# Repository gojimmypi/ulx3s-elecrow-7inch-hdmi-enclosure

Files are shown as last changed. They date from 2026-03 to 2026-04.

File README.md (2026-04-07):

# ULX3S Elecrow 7 inch HDMI Display Enclosure

This is an enclosure for the [ULX3S FPGA + ESP32](https://radiona.org/ulx3s/) development and educational board
for use with the [Elecrow 7 inch HDMI display](https://www.elecrow.com/rc070s-7-inch-1024-600-ips-hdmi-capacitive-touch-monitor.html),
such as [this one available on Amazon](https://www.amazon.com/dp/B08FMNDDSL).



The enclosure is not perfect. Some minor remaining ideas for improvement are in the [To-Do list](./TODO.md).

See related links:

- [ULX3S Crowd Supply Campaign](https://www.crowdsupply.com/radiona/ulx3s)
- [ULS3S from Mouser](https://www.mouser.com/c/?q=ulx3s)
- [Elecrow HDMI display from Amazon](https://www.amazon.com/dp/B08FMNDDSL) on Amazon
- [ulx3s.github.io](https://ulx3s.github.io/) for some sample ULX3S projects

## Warnings

- Choking hazard for small parts. Keep away from children and pets.
- Don't use external and internal HDMI concurrently. Pick one.
- Don't use USB Touch and USB Power connectors at the same time. Pick one.
- Experimental FPGA Programming of an HDMI display may result in pseudo "burn-in". See [YouTube video](https://www.youtube.com/watch?v=WJaRHJX4xYA) to resolve.

## Specification Summary

Designed with Autodesk Fusion for the [Prusa MK3S 3D Printer](https://help.prusa3d.com/product/mk3s) using PETG Filament.
Sliced with PrusaSlicer 2.9.4.

The latest [Prusa MK3S](https://help.prusa3d.com/product/mk3s) firmware was used: [`MK3S_MK3S+_FW_3.14.1_MULTILANG.hex`](https://www.prusa3d.com/downloads/firmware/prusa3d_fw_3_14_1_MK3S.zip).
There's a copy [here](./firmware/). Note this version is completely intolerant to intermittent sensor failures. See [MINTEMP BED error](https://help.prusa3d.com/article/mintemp-error-and-mintemp-bed_2169).

#### Default Fusion settings

- Refinement: Medium
- Surface Deviation: 0.036706 mm
- Normal Deviation: 15.00 (angular tolerance in degrees)
- Maximum Edge: 231.60045 mm (no practical limit)
- Aspect Ration: 21.5 (Controls how "skinny" triangles are allowed to be)

#### 3D Printer Settings

- Material: PETG
- Ambient temperature: > 75F
- Print Setting: 0.15 Quality (each layer thickness)
- Nozzle: 0.4 mm
- Filament: 1.75 mm
- First Layer: 240 degrees C
- Other layers: 236 degrees C
- Bed: 85 degrees C
- Otherwise defaults in PrusaSlicer version 2.9.4

Note the 0.4 mm nozzle and 0.15 layer height are coded in the Fusion parameters. ymmv with other print settings.

## 3D Printing Files

There are Autodesk Fusion STL files in the [STL](./STL/README.md) directory for printing to any device.

Prototypes were all created using PETG filament. Other filaments may be used. Note the snap-in nature of
the display expects the right (audio) side of the enclosure to have a bit of flex during assembly.

#### Prusa Files

The Pruse Slicer Project files and G-Code are in the [Prusa](./Prusa/README.md) directory.
Included are `PrusaSlicer_config_bundle.ini` files for the MK3S, but should adapt easily to other printers.

To [get started](./QUICK_START.md) quickly, printing all parts for the Prusa slicer, see:

- `Enclosure Display Side.3mf`<br />
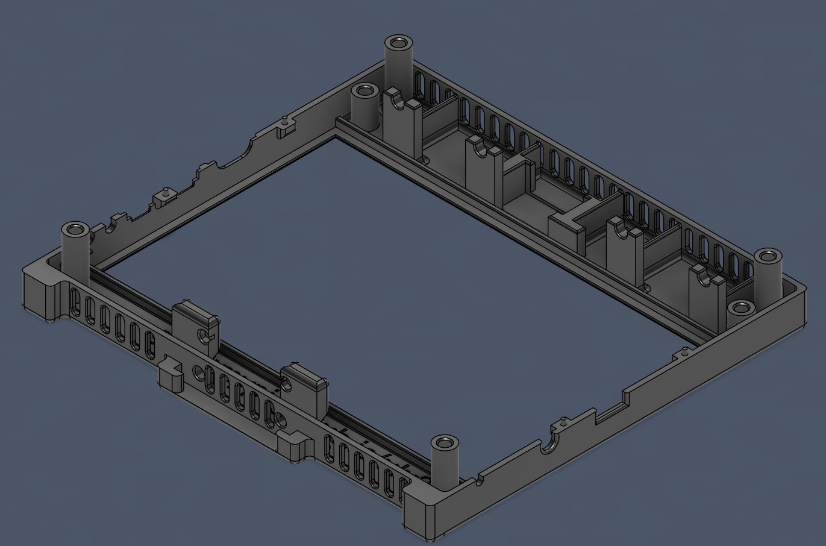
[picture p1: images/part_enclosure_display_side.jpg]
part_enclosure_display_side
   
- `Enclosure ULX3S Side.3mf`<br />
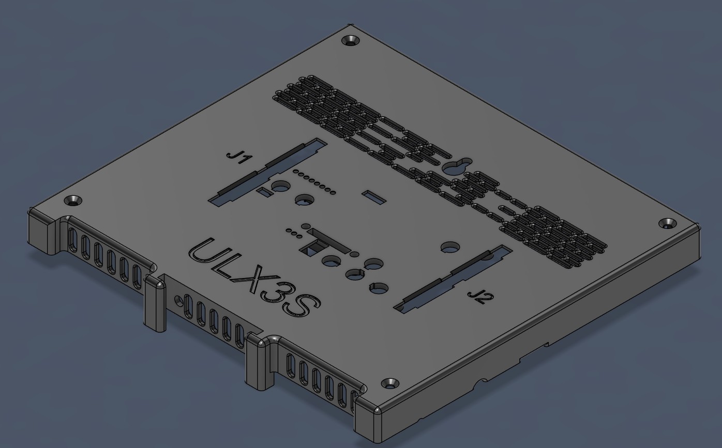
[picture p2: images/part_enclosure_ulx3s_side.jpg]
part_enclosure_ulx3s_side
 
- `Small parts.3mf`<br />
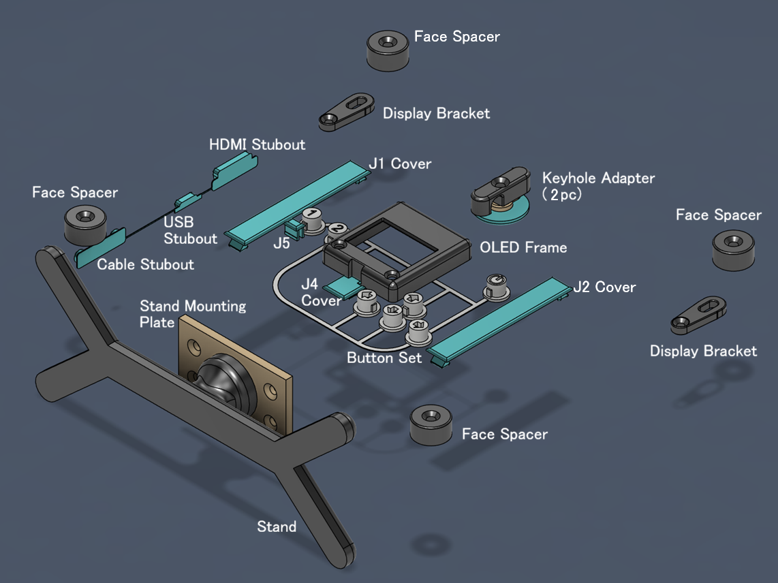
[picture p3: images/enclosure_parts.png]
part_ULX3S To RPi Elecrow Adapter
  
- `Adapter Base Plate Set.3mf`<br />
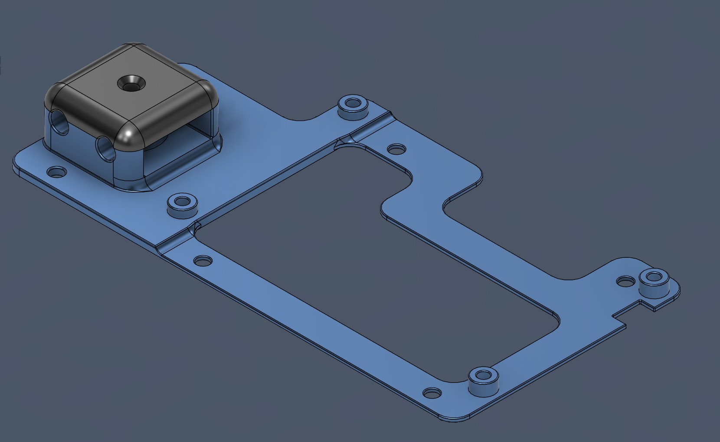
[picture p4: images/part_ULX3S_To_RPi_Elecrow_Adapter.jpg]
part_ULX3S To RPi Elecrow Adapter
  

Note that the buttons are includes in the small parts set. If a separate color is desired for only the buttons, see the `Button Set` files. <br />

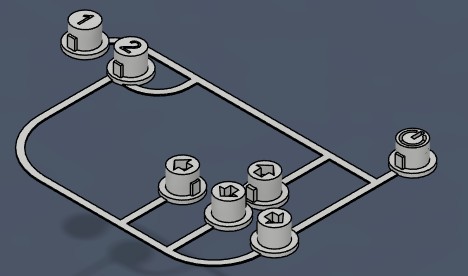
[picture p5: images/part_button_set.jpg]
part_button_set
- 

The "0.15 Quality" has some critical changes in the `User Presets - 0.15mm QUALITY @MK3 - ULX3S Project`
that were observed to make a difference between print success and failure.

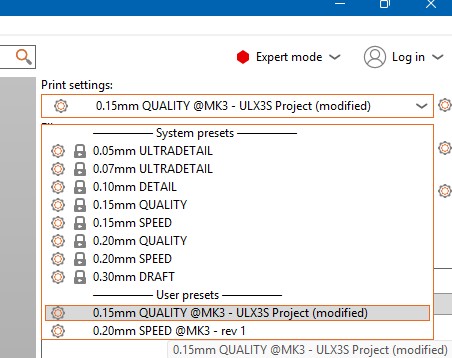
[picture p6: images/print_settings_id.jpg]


In particular not these changes from defaults:

- print_settings_id = 0.15mm QUALITY @MK3 - ULX3S Project

- seam_position = rear

- brim_width = 5 (can be set to zero if in a warm, stable environment)

- first_layer_speed = 15

- first_layer_extrusion_width = 0.5

- elefant_foot_compensation = 0.05

Other settings to consider:

- Increase infill to 20 - 30% (main print settings)

- Increase the number of perimeters from 2 to 3. (Print Settings - Layers and Perimeters - Vertical shells - Perimeters)

## Compatibility Issues

The Elecrow display was designed for the Raspberry Pi, not the ULX3S. As such there are some minor physical positioning items to consider:

- USB2 / US2 vs Speaker.

  When mounted directly on the Elecrow display, the second USB connector on the ULX3S does not have room to be plugged in with the default speaker position.

  Consider rotating the speaker at an angle to ensure the USB cable can be inserted.

  Plug in the speakers, mount the ULX3S to the display first, then consider USB cable routing before securing speakers to display.

- J2 Header vs Fan Header

  The onboard fan connector header for the Elecrow display fan is directly under some of the J2 header pins.
  The fit is so tight that soldered leads may need to be trimmed and/or the plastic header trimmed.

  It is unlikely that the fan header connector can be used. No fan is typically included with the display.

- Audio

  The Elecrow HDMI Display will typically pass through audio on the HDMI interface. For an FPGA board such as the ULX3S, the audio would _need to be implemented in HDL_.

  The external audio connector is for optional headphones.

  There's also an onboard audio connector for the ULX3S. There's an optional exit hole to route the audio out from the ULX3S.

- HDMI

  The ULX3S has a pin-_compatible_ GPDI (General-Purpose Differential Interface). To use this with an HDMI display, the appropriate HDL needs to be implemented on the FPGA. See the [Bruno Levy example](https://github.com/BrunoLevy/learn-fpga/tree/master/Basic/ULX3S/ULX3S_hdmi).

  Do **NOT** use the side panel Elecrow Display HDMI concurrently with the ULX3S connected internally.

  The mini-PC Board HDMI-to-HDMI connector is not specified as being included on all Elecrow product listing at various vendors. If _not_ included, there's room to use an [A1-A1 FPC (Flexible PC)](https://www.amazon.com/dp/B01787KZVG) HDMI Cable. Note some A1 cables reverse one of the HDMI connectors. The desired orientation is having both narrow sides in the same orientation:

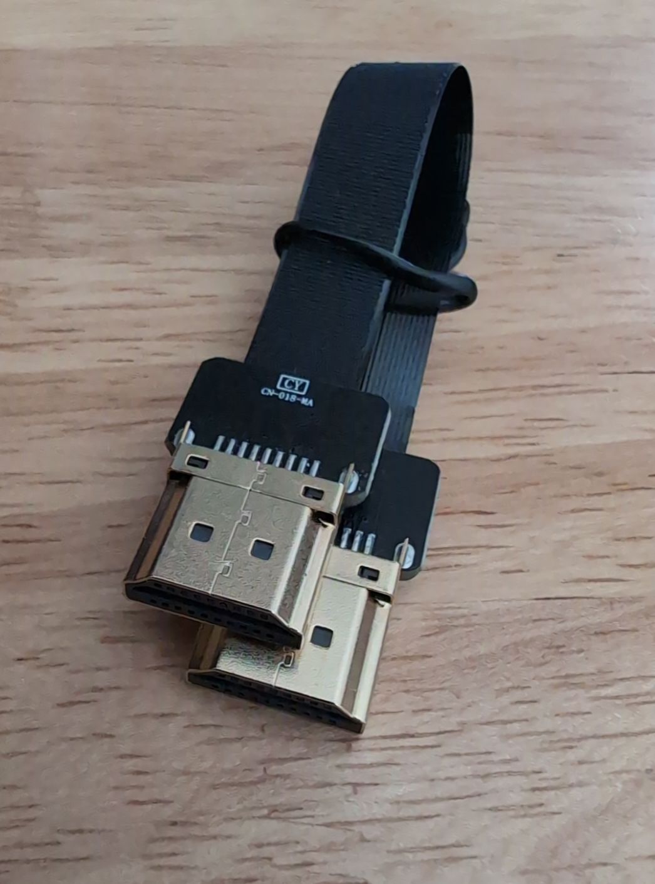
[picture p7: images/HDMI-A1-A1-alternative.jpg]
HDMI A1-A1 alternative
  

  Note when using the ribbon cable HDMI connector, there may be mechanical interference with optional internal fan and/or keyhole mount.

## Features

- Buttons for ULX3S: PWR, F1, F2, Left, Right, Up, Down
- Light pipe mounting blocks for `D0` - `D7` (blinky) and `D18` (PWREN), `D9` (TXLED), `D22` (WIFI): Tight fit 2mm fiber optic cable max diameter.
- External panel access to J1 and J2 GPIO 40 pin header with optional cover.
- External panel access to J3 (GND and WIFI_OFF: ESP32 EN)
- External panel access to J4 JTAG 6 pin header: `3v3`, `GND`, `TDO`, `TDI`, `TCK`, `TMS`.
- External Panel access to J5 VJ1 `+3v3` and `+2v5`, pin 2 is `2V5_3V3` (note: covered when using OLED frame)
- External Elecrow HDMI connection. (**WARNING**: Not to be used concurrently with ULX3S HDMI)
- External Micro-B USB connector for display power.
- External Micro-B USB connector for optional display touch control.
- External access to Display Brightness / Volume control.
- External SRRS mounting hole for ULX3S audio output.
- Audio: 3.5 mm jack with 4 contacts (analog stereo + digital audio or composite video)
- Optional mounting stand.
- Optional OLED display frame for [0.95" 7 pin SPI SSD1331 OLED Display](https://www.amazon.com/dp/B0711RKXB5/)
- Optional feet (same thickness as the OLED display frame) for using the display horizontally during development.
- Optional keyhole for wall mounting: Slightly offset to one side to balance internals.
- Optional internal slot for [25mm x 10mm 5V fan](https://www.amazon.com/dp/B07KRX9F99).
- Optional face screws for securing ULS3S directly to enclosure. Hole is nearly to surface, poke to use with 4 mm standoffs.
- Internal USB cable routing.
- Internal FPC HDMI cable routing.
- Exit holes for USB cables routed internally from ULX3S. See adapter strain relief block.
- Adjustable positioning for the display. See left and right display brackets.
- Air vents in the top and bottom. (assuming a vertical orientation of display)
- Optional `(Hex Head)`-suffixed files for Stand Mounting Plate and Display Brackets where screw clearance is critical. The default is Philips.

## Assembly

The enclosure was designed to have the ULX3S mounted inside. This means that the USB connectors require internal cable routing.

See [ASSEMBLY.md](./ASSEMBLY.md) for further details.

### Display

The display snaps into place. There is a bit of up-down play available, as the technical diagram did not reference the display positon with respect to the attached display driver PC board. Once snapped into place, manually align the USB ports on the left and the audio cable on the right. Plus in a USB cable and audio cable to ensure proper alignment, then fix the display in place with the brackets.

Insert a USB Micro-B cable on one side of the enclosure and ideally an audio cable on the other to ensure alignment of the display board with the enclosure.

Once alignment has been verified, install the display mounting brackets and tighten the screws.

### Speakers

Ensure the ULX3S board is mounted first. There's a tight fit between the speaker and PC Board.

### HDMI Connection

There's a tight vertical clearance between the HDMI-HDMI connector board at the underside of the ULX3S. Consider insulsting kapton or electrical tape.

**WARNING** Do not use the external HDMI connection while the ULX3S is connected internally. Consider keeping a cover in place.

## Files

- [bitfiles](./bitfiles/README.md) - Prebuilt FPGA files to get started quickly.
- [firmware](./firmware/README.md) - Firmware `.hex` files for Prusa MK3S printers.
- [Fusion/ExportedParameters.csv](./Fusion/ExportedParameters.csv) - Parameters defined in Autodesk Fusion.
- [Prusa](./Prusa/README.md) - Prusa Slicer Projects and G-Code for the MK3S.
- [Prusa/PrusaSlicer_config_bundle.ini](./Prusa/PrusaSlicer_config_bundle.ini) - Prusa MK3S settings used.
- [STL](./STL/README.md) - Enclosure and all parts in STL format printed from Autodesk Fusion.

## Published Files

Currently the original official; files are only located at <https://github.com/gojimmypi/ulx3s-elecrow-7inch-hdmi-enclosure>

[x] <https://cults3d.com/en/3d-model/various/ulx3s-hdmi-enclosure-for-the-elecrow-7-inch-display>

TODO publish to other locations:

- <https://www.printables.com/@gojimmypi_17688>
- <https://www.thingiverse.com/gojimmypi/designs>
- <https://www.etsy.com/people/gojimmypi>
- <https://www.elecrow.com/share-projects.html>
- <https://grabcad.com/gojimmypi-1/models>
- <https://thangs.com/designer/gojimmypi>
- <https://www.myminifactory.com/users/gojimmypi>
- <https://makerworld.com/en/@gojimmypi>

## License

See [LICENSE](./LICENSE). In short:

The [Creative Commons Attribution - NonCommercial - ShareAlike 4.0 International (CC BY-NC-SA 4.0) license](https://creativecommons.org/licenses/by-nc-sa/4.0/)
lets anyone copy, share, and modify this enclosure design worldwide and royalty-free, as long as users

- (1) give proper attribution
- (2) use it only for non-commercial purposes
- (3) distribute any modified versions under the same license (ShareAlike).

It is irrevocable provided users follow the terms, does not grant patent or trademark rights,
and includes strong warranty and liability disclaimers (the work is provided "as-is").
If someone violates the terms, their rights terminate automatically but can be reinstated
if they fix the issue within 30 days. In short, it allows open collaboration and remixing,
but blocks commercial use and requires derivatives to stay under the same non-commercial license.

A commercial license is available. Contact me: <https://gojimmypi.github.io/>

## Links

- [Prusa How to update firmware (MK3S+/MK3S/MK3)](https://help.prusa3d.com/article/how-to-update-firmware-mk3s-mk3s-mk3_2227)
- [CrowdSupply ulx3s](https://www.crowdsupply.com/radiona/ulx3s)
- [Prusa Help: Layers and perimeters, detect thin walls](https://help.prusa3d.com/article/layers-and-perimeters_1748#detect-thin-walls)
- [Prusa Help: Seam position](https://help.prusa3d.com/article/seam-position_151069)
- [Digilent Pmod and FPGA: Connection Guide](https://digilent.com/blog/where-to-plug-in-your-pmod-fpga/)
- [openFPGALoader WEB interface - ofl.trabucayre.com](https://ofl.trabucayre.com/), from [github.com/trabucayre/openFPGALoader](https://github.com/trabucayre/openFPGALoader)
- [ULX3S examples from the Legendary Lawrie Griffiths](https://github.com/lawrie/ulx3s_examples/tree/master)

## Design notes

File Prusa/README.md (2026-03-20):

# Prusa Files for the ULX3S Elecrow 7 Inch HDMI Enclosure

## Project Files

### Prusa Slicer Main Body and Print Set Projects

- Enclosure Display Side.3mf
- Enclosure ULX3S Side.3mf

### Prusa Slicer Individual Part Projects

- Adapter Base Plate Set.3mf
- Adapter Base Plate Spacer  2.3mf
- Adapter Base Plate Spacer.3mf
- Adapter Base Plate.3mf
- Button Set.3mf
- Display Bracket Left.3mf
- Display Bracket Right.3mf
- Enclosure Display Side.3mf
- Enclosure ULX3S Side.3mf
- HDMI Stubout.3mf
- J1 Cover.3mf
- J2 Cover.3mf
- J3 Cover.3mf
- J4 Cover.3mf
- Keyhole External Adapter.3mf
- Keyhole Face Insert.3mf
- Keyhole Internal Adapter.3mf
- Light Pipe Sample.3mf
- OLED Frame.3mf
- Rear Foot 1.3mf
- Rear Foot 2.3mf
- Rear Foot 3.3mf
- Rear Foot.3mf
- Small parts.3mf
- Stand Mounting Plate.3mf
- Stand.3mf
- ULX3S Face Covers.3mf
- USB Restraint Cap.3mf

### Prusa Slicer Individual Part Mockup Project

- Display Mockup.3mf
- Keychain Ring Mockup.3mf

## G-Code Files

The G-Code files were generated for a Prusa MK3S+ printer.

### Prusa Slicer Main Body and Print Set G-Code

When printing, the two enclosure halves and the small parts set can be used instead of printing each part individually.

The Adapter Base Plat Set is included in the Small Parts and can also be printed separately as a set.

- Adapter Base Plate Set_0.15mm_PETG_MK3S_1h21m.gcode
- Enclosure Display Side_0.15mm_PETG_MK3S_7h5m.gcode
- Enclosure ULX3S Side_0.15mm_PETG_MK3S_8h55m.gcode
- Small parts_0.15mm_PETG_MK3S_5h5m.gcode

### Prusa Slicer Individual Part G-Code

- Adapter Base Plate Spacer  2_0.15mm_PETG_MK3S_5m.gcode
- Adapter Base Plate Spacer_0.15mm_PETG_MK3S_5m.gcode
- Adapter Base Plate_0.15mm_PETG_MK3S_59m.gcode
- Button Set_0.15mm_PETG_MK3S_19m.gcode
- Display Bracket Left_0.15mm_PETG_MK3S_6m.gcode
- Display Bracket Right_0.15mm_PETG_MK3S_6m.gcode
- Enclosure Display Side_0.15mm_PETG_MK3S_7h5m.gcode
- Enclosure ULX3S Side_0.15mm_PETG_MK3S_8h55m.gcode
- HDMI Stubout_0.15mm_PETG_MK3S_6m.gcode
- J1 Cover_0.15mm_PETG_MK3S_7m.gcode
- J2 Cover_0.15mm_PETG_MK3S_7m.gcode
- J3 Cover_0.15mm_PETG_MK3S_2m.gcode
- J4 Cover_0.15mm_PETG_MK3S_3m.gcode
- Keyhole External Adapter_0.15mm_PETG_MK3S_12m.gcode
- Keyhole Face Insert_0.15mm_PETG_MK3S_3m.gcode
- Keyhole Internal Adapter_0.15mm_PETG_MK3S_5m.gcode
- OLED Frame_0.15mm_PETG_MK3S_20m.gcode
- Rear Foot 1_0.15mm_PETG_MK3S_11m.gcode
- Rear Foot 2_0.15mm_PETG_MK3S_11m.gcode
- Rear Foot 3_0.15mm_PETG_MK3S_11m.gcode
- Rear Foot_0.15mm_PETG_MK3S_11m.gcode
- Stand Mounting Plate_0.15mm_PETG_MK3S_24m.gcode
- Stand_0.15mm_PETG_MK3S_1h16m.gcode
- ULX3S Face Covers_0.15mm_PETG_MK3S_16m.gcode
- USB Restraint Cap_0.15mm_PETG_MK3S_18m.gcode

### Prusa Slicer Individual Part Mockup G-Code

- Display Mockup_0.15mm_PETG_MK3S_5h14m.gcode
- Keychain Ring Mockup_0.15mm_PETG_MK3S_11m.gcode
- Light Pipe Sample_0.15mm_PETG_MK3S_19m.gcode

### Prusa Slicer MK3S Settings

- PrusaSlicer_config_bundle v1.ini
- PrusaSlicer_config_bundle.ini
- PrusaSlicer_config_bundle_original.ini
-

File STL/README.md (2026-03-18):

# STL Files

- Button Set.stl
- Display Bracket Left.stl
- Display Bracket Right.stl
- Display Mockup.stl
- Enclosure Display Side.stl
- Enclosure ULX3S Side.stl
- HDMI Stubout.stl
- J1 Cover.stl
- J2 Cover.stl
- J3 Cover.stl
- J4 Cover.stl
- Keychain Mockup.stl
- Keyhole External Adapter.stl
- Keyhole Face Insert.stl
- Keyhole Internal Adapter.stl
- Light Pipe Sample.stl
- OLED Frame.stl
- Rear Foot 1.stl
- Rear Foot 2.stl
- Rear Foot 3.stl
- Rear Foot.stl
- Stand Mounting Plate.stl
- Stand.stl
- ULX3S Mockup.st

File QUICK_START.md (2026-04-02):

# Quick Start

The [ASSEMBLY](./ASSEMBLY.md) instructions contain details for the various options.

There are only 3 essential parts:

| Part | Description |
| ---- | --- |
| <a href="./images/part_ULX3S_To_RPi_Elecrow_Adapter.jpg" target="_blank">part_ULX3S To RPi Elecrow Adapter</a> | Adapter Mounting Bracket with internal USB restraint |
| <a href="./images/part_enclosure_ulx3s_side.jpg" target="_blank">part_enclosure_ulx3s_side</a> | Enclosure ULX3S Side |
| <a href="./images/part_enclosure_display_side.jpg" target="_blank">part_enclosure_display_side</a> | Enclosure Display Side |

The holes for heat set inserts are size for the type with a little lip on one end as seen on the left:

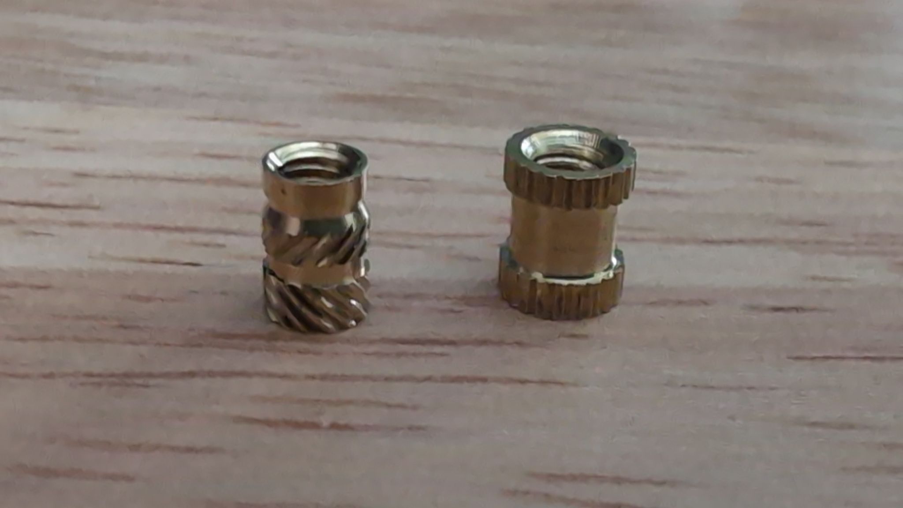
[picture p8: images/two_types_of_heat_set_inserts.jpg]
two types of heat set inserts


Most screws are [Philips M3](https://www.amazon.com/dp/B0FZTYBXPY). The HDMI Display use M2.5, and the OLED mount uses M2.

[These M3 inserts](https://www.amazon.com/dp/B0FWWW8VP1) were used:

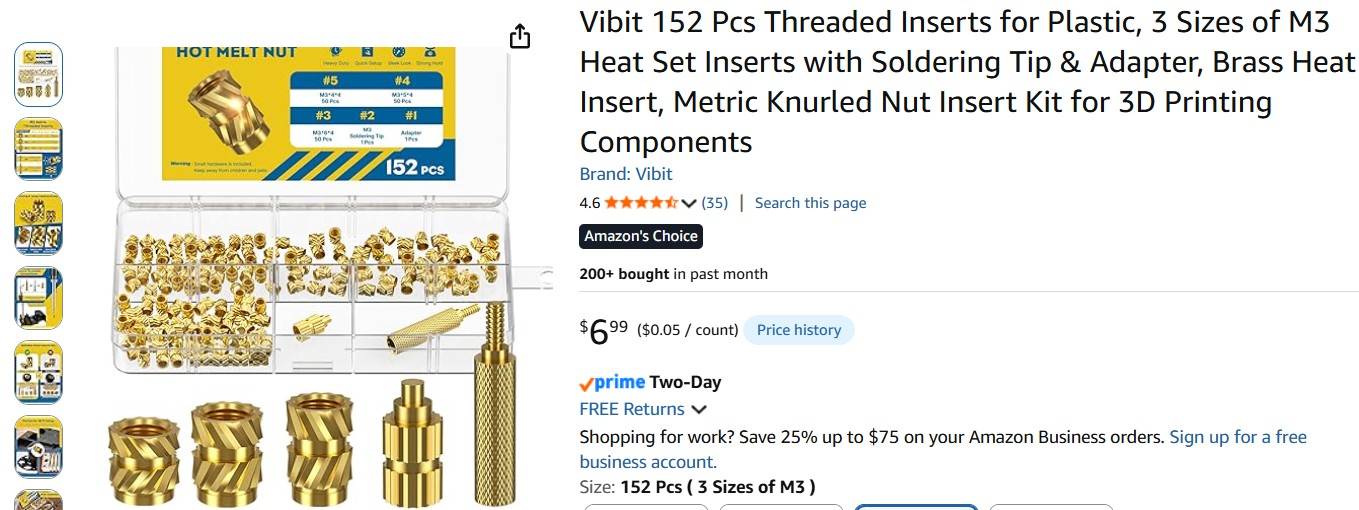
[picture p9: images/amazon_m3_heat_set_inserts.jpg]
amazon m3 heat set inserts


## Assembly

Secure the mounting adapter to the display, then attach the ULX3S to the adapter.

Be sure to install the A1-A1 HDMI connector between the ULX3S and the display.

See the [ASSEMBLY](./ASSEMBLY.md) instructions for more details.

## Bit files

See the pre-built binaries in the [bitfiles](./bitfiles/README.md) directory.

```bash
fujprog HDMI_test_hires.bit
```

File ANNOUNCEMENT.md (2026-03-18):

# New 3D Printable ULX3S Enclosure for the Elecrow 7 inch HDMI Display

The ULX3S community continues to build amazing projects ranging from retrocomputers to FPGA graphics demos. A new open source, 3D printable enclosure now makes it easy to combine the ULX3S with a 7 inch HDMI display to create a compact, portable FPGA workstation.

For a great overview of what people are building, see the extensive collection of examples at:

https://ulx3s.github.io/

One common request has been a clean way to combine the ULX3S with a display for portable demos and development. Community member gojimmypi has designed an open source, 3D printable enclosure that integrates the ULX3S with a popular 7 inch HDMI display.

An open source enclosure design is now available here:

https://github.com/gojimmypi/ulx3s-elecrow-7inch-hdmi-enclosure

## A Portable FPGA Workstation

The enclosure turns the ULX3S into a compact FPGA workstation by combining:

- ULX3S FPGA + ESP32 board
- Elecrow 7 inch HDMI display
- External buttons and controls
- Accessible development interfaces

The result is a portable system that is well suited for demonstrations, classroom environments, and FPGA development setups where a separate monitor is not convenient.

## Designed for Development

A key goal of the enclosure is to keep the ULX3S fully usable while mounted inside. Important interfaces remain accessible so developers can continue experimenting without removing the board.

Features include:

- External buttons for ULX3S controls
  (Power, F1, F2, Left, Right, Up, Down)

- Light pipe mounts for FPGA status LEDs
  (D0 through D7, TXLED, WiFi, and power)

- External access to important headers
  - J1 and J2 GPIO headers
  - J3 ESP32 control pins
  - J4 JTAG programming header
  - J5 power rails

- Access to display brightness and volume controls

- External audio jack routing

This allows you to program, debug, and interact with FPGA projects without opening the enclosure.

## Built Around the Elecrow 7 inch HDMI Display

The enclosure is designed around the widely available Elecrow 7 inch 1024x600 IPS HDMI display. Although originally designed for Raspberry Pi systems, it works well with the ULX3S when using the board GPDI HDMI interface and appropriate FPGA HDL.

This combination creates a convenient platform for projects such as:

- FPGA graphics demos
- retrocomputer cores
- FPGA user interfaces
- educational FPGA experiments

## Designed for Makers

The enclosure was designed in Autodesk Fusion and optimized for 3D printing on a Prusa MK3S using PETG filament.

The design includes several practical details:

- Internal routing for USB and HDMI cables
- Adjustable display mounting brackets
- Ventilation openings for airflow
- Optional internal 25 mm cooling fan mount

Optional features allow the enclosure to be customized for different setups:

- OLED status display mount
- Desktop stand configuration
- Horizontal development feet
- Wall mount keyhole
- Internal cable strain relief

## Open Source Hardware

The enclosure design is released under the Creative Commons BY-NC-SA 4.0 license, allowing the community to:

- print the enclosure
- modify the design
- share improvements

Commercial licensing is also available from the author.

## Continuing Progress

Development continues across the ULX ecosystem.

Work is progressing on the upcoming campaigns for:

- ULX4M
  https://www.crowdsupply.com/intergalaktik/ulx4m

- ULX5M, recently presented at CERN
  https://radiona.org/fpga-ulx5m-presented-cern/

ULX3S boards remain available from:

- Crowd Supply
  https://www.crowdsupply.com/radiona/ulx3s

- Mouser Electronics
  https://www.mouser.com/c/?q=ulx3s

We are excited to see how the community continues to build new projects and tools around the ULX platform.

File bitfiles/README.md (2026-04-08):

# Prebuilt FPGA Files

Known working `.bit` files to be used for quick start and testing.

- [HDMI_test_hires.bit](./HDMI_test_hires.bit) from Bruno's [learn FPGA repo](https://github.com/BrunoLevy/learn-fpga/tree/master/Basic/ULX3S/ULX3S_hdmi).
- [passthru_implementation_12F.bit](./passthru_implementation_12F.bit) from [ulx3s-examples](https://github.com/ulx3s/ulx3s-examples/tree/master/bin). See ESP32 [passthru](https://github.com/ulx3s/ulx3s-examples/tree/master/passthru)
- [passthru_implementation_42F.bit](./passthru_implementation_45F.bit)
- [passthru_implementation_85F.bit](./passthru_implementation_85F.bit)
- `fujprog-v48-win64.exe` Pre-compiled Windows executable.
- <https://github.com/emard/ulx3s-binother>  collection of functional binary files and uploaders to quickstart

## Programming

The Windows executable can be called from WSL:

``` bash
cd /mnt/c/workspace/ulx3s-elecrow-7inch-hdmi-enclosure/bitfiles

 ./fujprog-v48-win64.exe "C:\workspace\ulx3s-elecrow-7inch-hdmi-enclosure\bitfiles\HDMI_test_hires.bit"
 ```

## Build Tools

See

- <https://github.com/kost/fujprog>

## Other tests

- HDMI [test and exercise video](https://www.youtube.com/watch?v=WJaRHJX4xYA). (reminder to not plug in external HDMI when also using ULX3S HDMI internally)

## Links

- <https://github.com/emard/ulx3s>

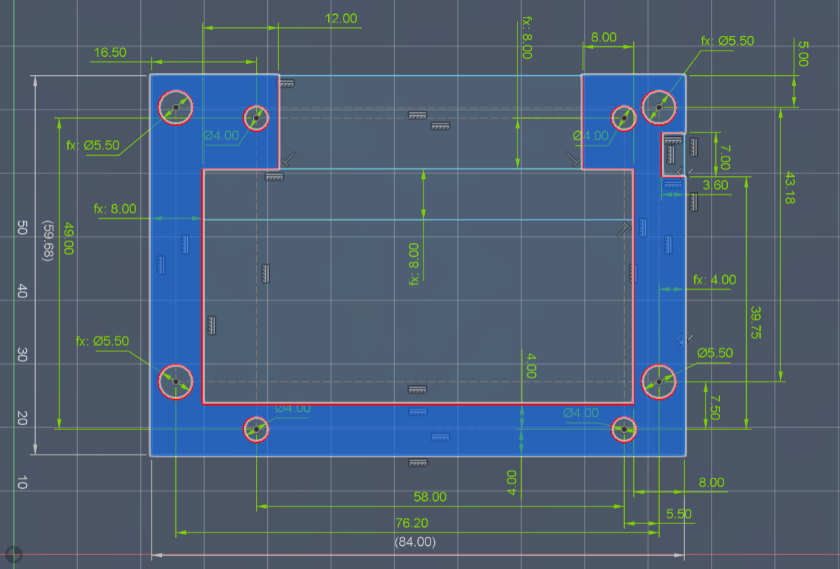
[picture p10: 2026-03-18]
images/ULX3S-Bracket-Dimensions.PNG

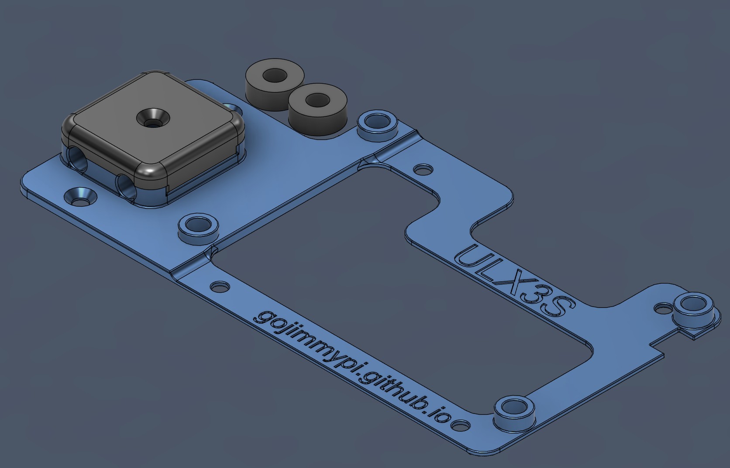
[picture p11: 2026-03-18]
images/ULX3S_To_RPi_Elecrow_Adapter.jpg

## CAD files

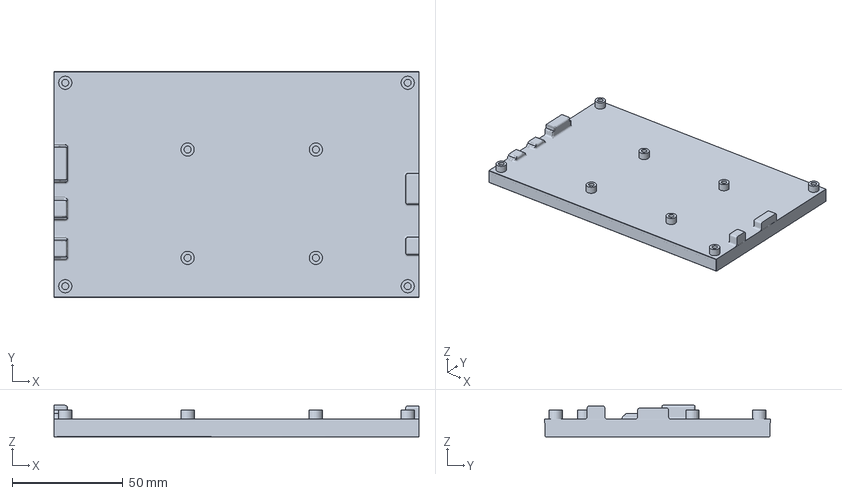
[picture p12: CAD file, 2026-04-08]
Prusa/Display Mockup.3mf
165.1 x 102.2 x 14.3 mm

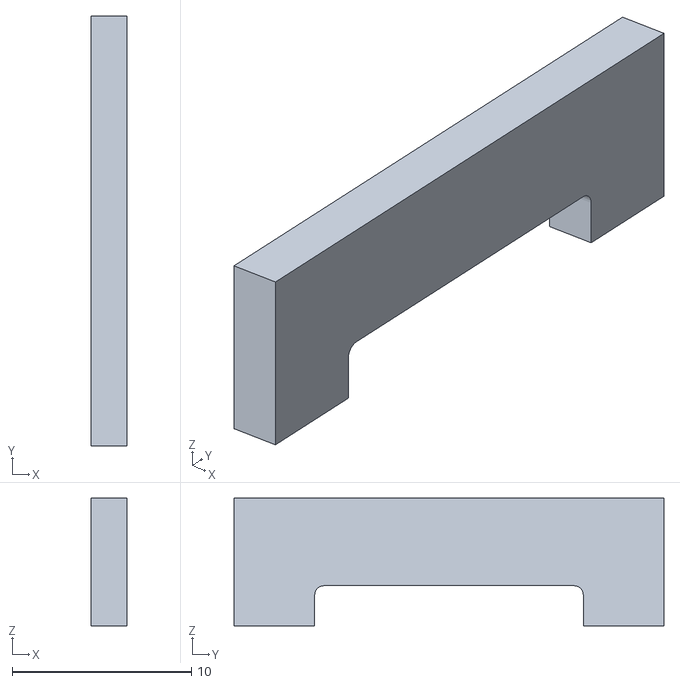
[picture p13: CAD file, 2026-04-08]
STL/HDMI Part 2 Test.stl
2.00 x 24.0 x 7.15

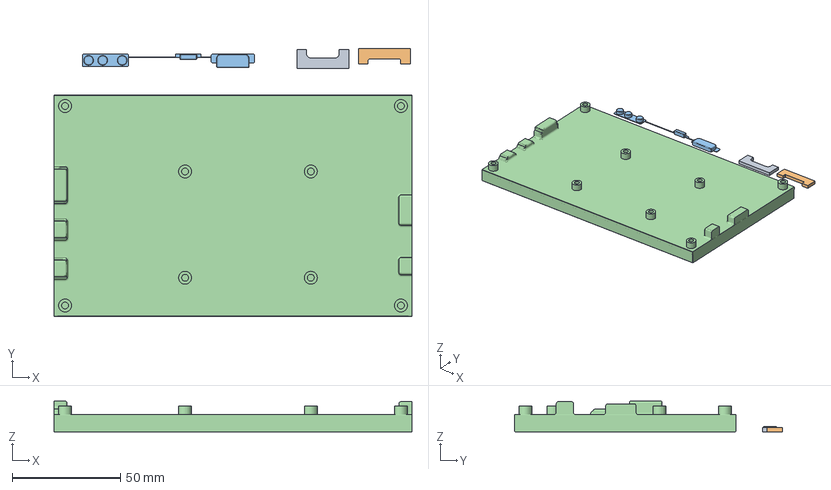
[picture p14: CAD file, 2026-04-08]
Prusa/HDMI Mockup Test.3mf
165.1 x 123.7 x 14.3 mm
HDMI Part 1 Test.stl
HDMI Part 2 Test.stl
HDMI Stubout.stl
Display Mockup.stl

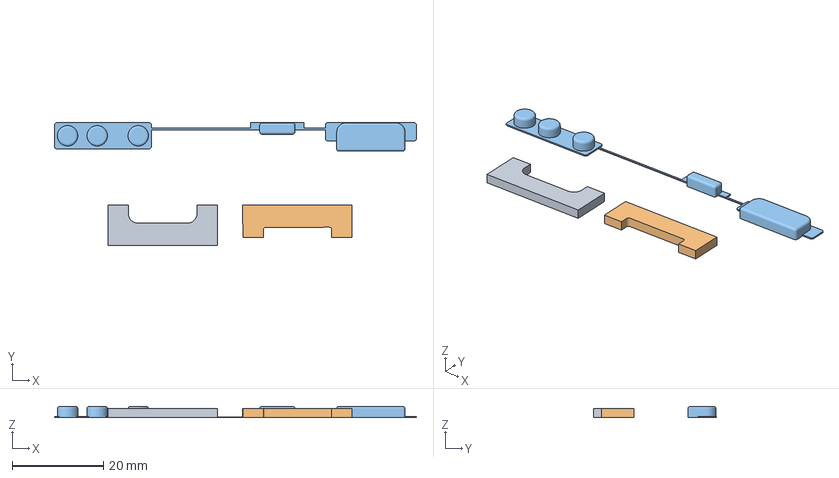
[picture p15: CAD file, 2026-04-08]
Prusa/HDMI Test.3mf
79.4 x 26.9 x 2.50 mm
HDMI Part 1 Test.stl
HDMI Part 2 Test.stl
HDMI Stubout.stl

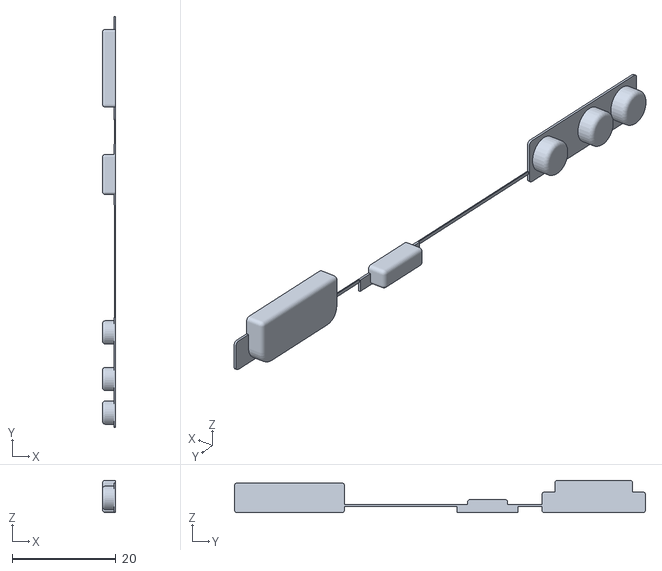
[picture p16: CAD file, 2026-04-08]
STL/HDMI Stubout.stl
2.50 x 79.4 x 6.25

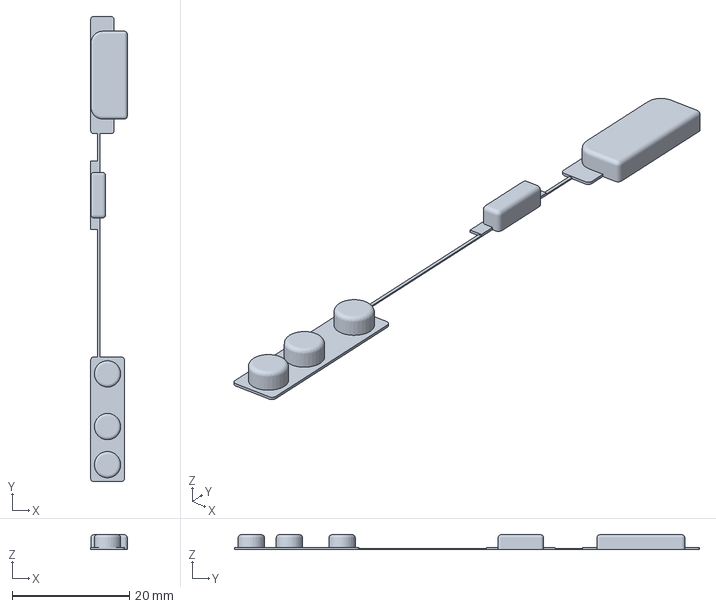
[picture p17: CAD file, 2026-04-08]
Prusa/HDMI Stubout.3mf
6.25 x 79.4 x 2.50 mm

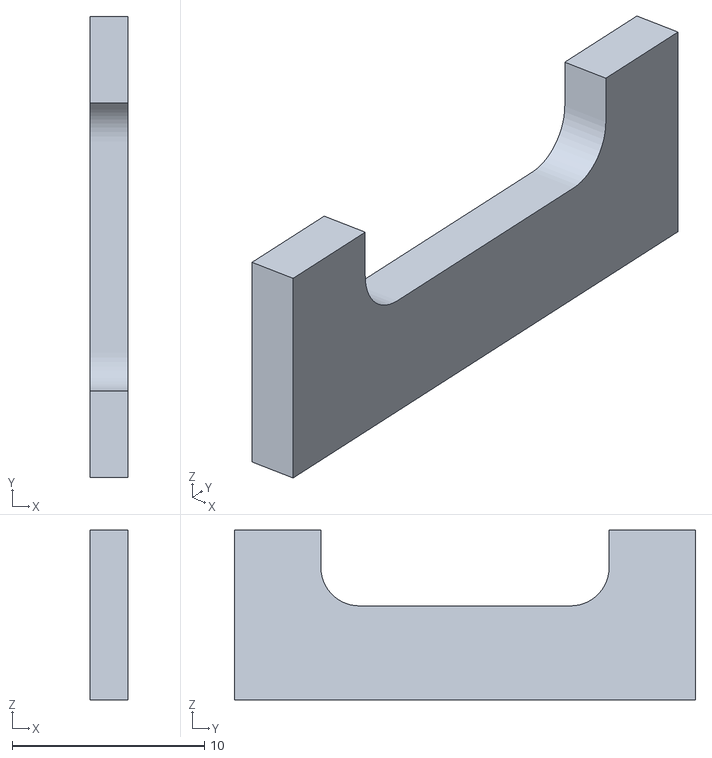
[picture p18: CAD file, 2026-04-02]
STL/HDMI Part 1 Test.stl
2.00 x 24.0 x 8.85

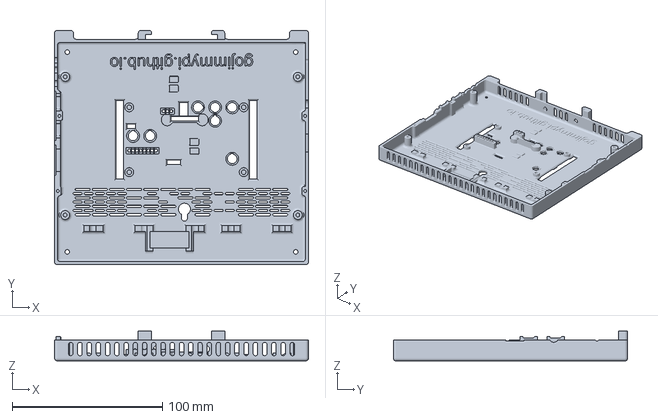
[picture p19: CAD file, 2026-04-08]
Prusa/Enclosure ULX3S Side.3mf
169.1 x 156.1 x 20.0 mm

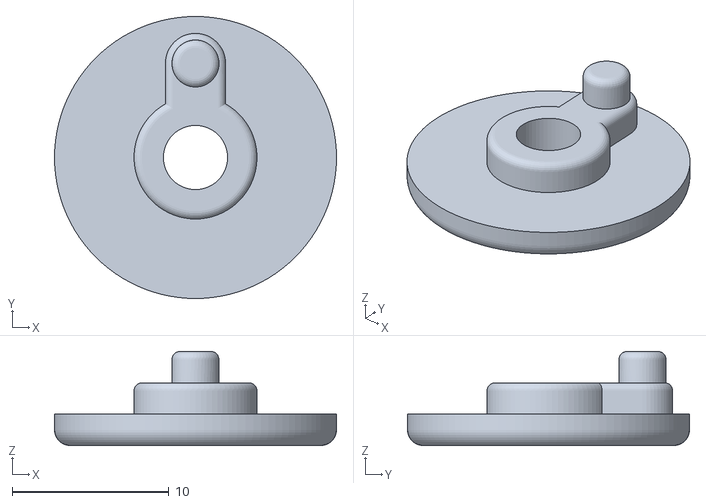
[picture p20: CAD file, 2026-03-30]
STL/Keyhole Internal Adapter.stl
18.0 x 18.0 x 6.00

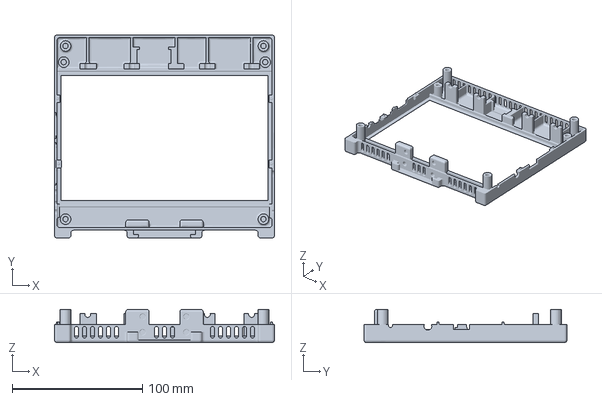
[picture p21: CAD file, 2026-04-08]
Prusa/Enclosure Display Side.3mf
169.1 x 156.1 x 25.5 mm

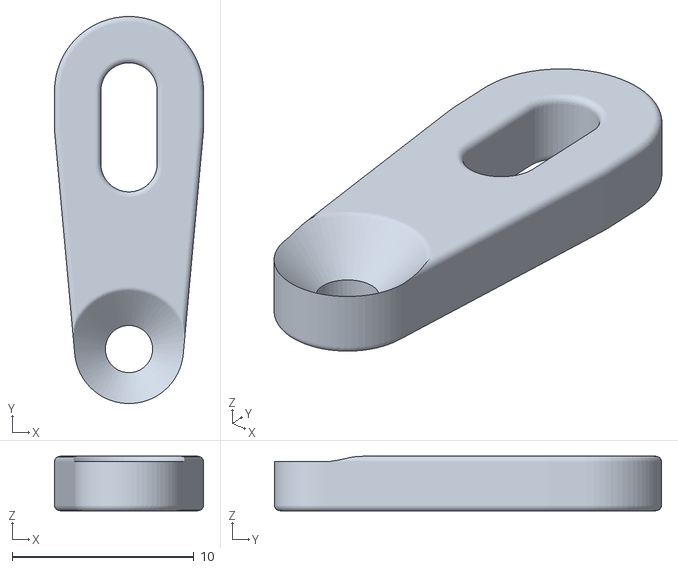
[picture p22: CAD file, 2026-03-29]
STL/Display Bracket Left (Hex Head).stl
8.20 x 21.3 x 3.00

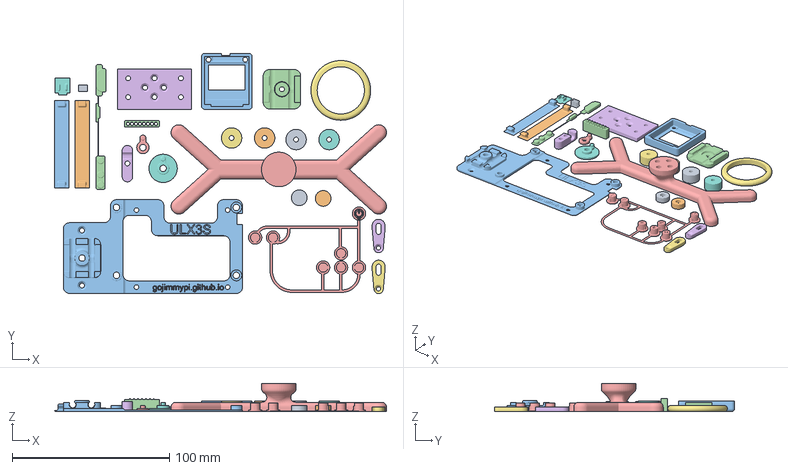
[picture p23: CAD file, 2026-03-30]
Prusa/Small parts.3mf
211.1 x 152.8 x 18.0 mm
Adapter Base Plate Spacer.stl
Adapter Base Plate Spacer 2.stl
Adapter Base Plate.stl
USB Restraint Cap.stl
Stand.stl
Stand Mounting Plate.stl
Rear Foot.stl
Rear Foot 3.stl
Rear Foot 2.stl
Rear Foot 1.stl
OLED Frame.stl
Light Pipe Sample.stl
Keyhole Face Insert.stl
Keyhole External Adapter.stl
Keychain Mockup.stl
J4 Cover.stl
J3 Cover.stl
J2 Cover.stl
J1 Cover.stl
HDMI Stubout.stl
Button Set.stl
Display Bracket Left.stl
Display Bracket Right.stl
Keyhole Internal Adapter.stl

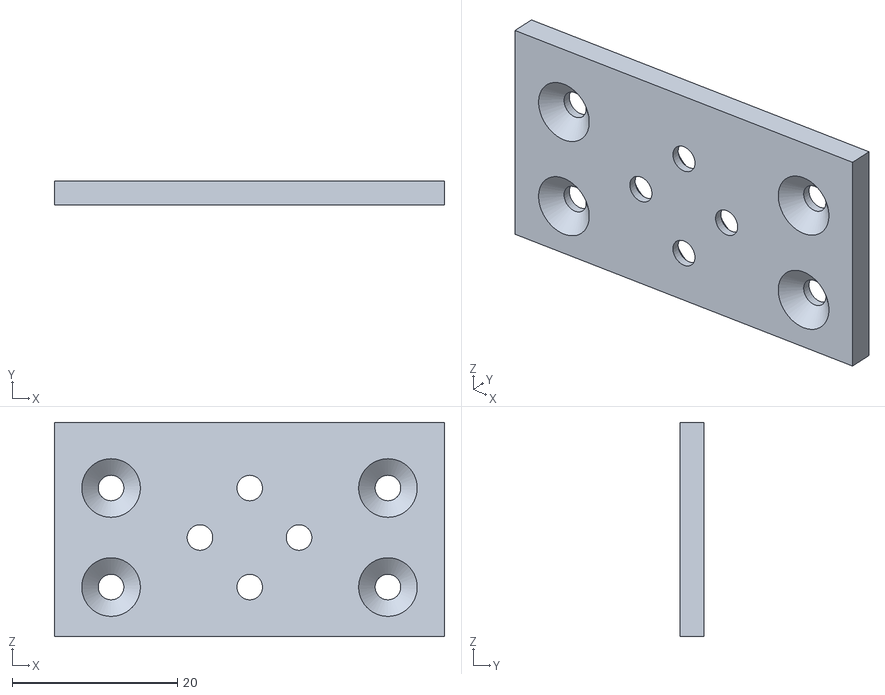
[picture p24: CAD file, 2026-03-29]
STL/Stand Mounting Plate (Hex Head).stl
47.2 x 2.95 x 25.9

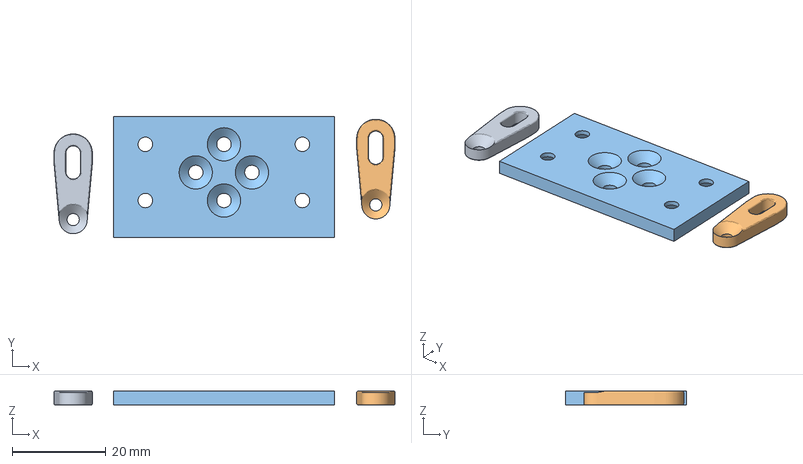
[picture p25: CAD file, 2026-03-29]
Prusa/Mounting Plate and Display Brackets (Heax Head).3mf
72.8 x 26.0 x 3.00 mm
Display Bracket Left.stl
Display Bracket Right.stl
Stand Mounting Plate.stl

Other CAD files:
STL/Display Mockup.stl
STL/Display Bracket Right (Hex Head).stl
Prusa/Keyhole Internal Adapter.3mf
STL/OLED Frame.stl
Prusa/Adapter Base Plate Set.3mf
Prusa/Adapter Base Plate Spacer 2.3mf
Prusa/Adapter Base Plate Spacer.3mf
Prusa/Adapter Base Plate.3mf
Prusa/Button Set.3mf
Prusa/Display Bracket Left.3mf
Prusa/Display Bracket Right.3mf
Prusa/J1 Cover.3mf
Prusa/J2 Cover.3mf
Prusa/J3 Cover.3mf
Prusa/J4 Cover.3mf
Prusa/Keychain Ring Mockup.3mf
Prusa/Keyhole External Adapter.3mf
Prusa/Keyhole Face Insert.3mf
Prusa/Light Pipe Sample.3mf
Prusa/OLED Frame.3mf
Prusa/Rear Foot 1.3mf
Prusa/Rear Foot 2.3mf
Prusa/Rear Foot 3.3mf
Prusa/Rear Foot.3mf
Prusa/Stand Mounting Plate.3mf
Prusa/Stand.3mf
Prusa/ULX3S Face Covers.3mf
Prusa/USB Restraint Cap.3mf
STL/Adapter Base Plate Spacer 2.stl
STL/Adapter Base Plate Spacer.stl
STL/Button Set.stl
STL/Display Bracket Left.stl
STL/Display Bracket Right.stl
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

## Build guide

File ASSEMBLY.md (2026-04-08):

# Assembly

This document describes how to assemble the [ULX3S](https://ulx3s.github.io/) enclosure for the [Elecrow 7 inch display](https://www.amazon.com/dp/B08FMNDDSL).

There are several similar displays. This enclosure is designed for the following model:

> "_ELECROW 7 Inch Touchscreen Monitor for Raspberry Pi - 1024x600 IPS Capacitive Touch Screen HD Mini LCD Display with Stand Compatible with Raspberry Pi 5/4B/3B+/3B, BB Black_".

Note: This display model has no visible front-facing mounting tabs with screw holes, unlike some similar displays.

If a display is not used, there's an optional blank panel mock-up available instead. See the related `Display Mockup` files.

## Licensing and Marketing Affiliation

The enclosure is open source, with a paid commercial license available. See the [LICENSE](./LICENSE) file.

There are no paid marketing affiliations. Related product links are included for convenience only.

## Before You Start

- Verify all printed parts are free of defects

- Confirm you have all required screws and inserts

- Test-fit critical components before final assembly

- Read all instructions at least once before beginning

- Review the minor [Compatibility Issues](https://github.com/gojimmypi/ulx3s-elecrow-7inch-hdmi-enclosure?tab=readme-ov-file#compatibility-issues) in the main README file.

## Common Mistakes

- Using the wrong HDMI connector (only A1-A1 fits)

- Installing inserts too hot (causes deformation)

- Blocking internal support posts with wires

- Cutting light pipes too long (causes enclosure bulge)

## Tips for Success

Pre-read all instructions to the end before proceeding.

Re-read all instructions before proceeding. (Yes repeated here, Read the fine manual!)

- For any project using screws, consider [thread locker purple](https://www.amazon.com/dp/B000HBGHFY).

- When multiple screws are used in a given assembly piece, insert them all first and then gradually tighten them in opposite corner order succession.

- Metal threaded inserts may possibly be inserted without heating. This is not advised. Use care.

- A soldering iron without a temperature adjuster can be hundreds of degrees too hot for use with threaded inserts,
particularly the small ones used here. A [vertical heat set press tool](https://www.amazon.com/dp/B0DHKPHKJZ) works well.

- When using a heat-set tool, beware that the brass heating end looks very similar to the brass insert. Do not press any insert beyond the depth of the part face.

- Hex head screws are generally easier to install as compared to Philips (cross) or slotted screws.

- Use caution when subjecting plastic parts to mechanical stress. Ensure there's no debris, strings, or other print-time errors. Consider sanding to fit rather than using force.

- Consider optional internal speaker placement. The default orientation may be problematic. Install speakers last.

- As the buttons are very small, an accent color can optionally be added to the engraved symbols on the surface of the buttons prior to assembly.

- Ensure any internal electrical connectors are free of debris before beginning assembly.

- If there's a smooth end on the screw heat-set inserts, that end goes in first.

- Practice on the light block sample before attempting to insert fiber optic light pipes in the enclosure face.

## Key Measurements

- Minimum 4.9 mm clearance for buttons. Current: 3.4 mm distance, 2.1 mm base, 1 mm face offset
- Mechanical fit is typically 0.1 mm or 0.15 mm
- Parts were designed and printed assuming a 0.4 mm nozzle and 0.15 mm layer height.
- 3D printed in 25C (80F) ambient environment, with no brim, on a textured sheet, cleaned with IPA before each use.

## Filament

Tested with [Creality PETG 3D Printer Filament 1.75 mm](https://www.amazon.com/dp/B0C8NP63GD) and [Prusament PETG Jet Black](https://www.prusa3d.com/product/prusament-petg-jet-black-1kg/).

The Prusament has been very successful and robust for years.

Some deep-spool tangles were encountered for the first time using Creality. Their [response](./images/creality_support_reply.jpg)?

> respool your spools to prevent tangling on your future printing.

See also these suggested tangle prevention techniques:

- <https://www.youtube.com/watch?v=PaUfrRCd258>
- <https://www.youtube.com/watch?v=uf66_3bzIgc>

Untested yet, but next non-Prusament filament test will be Polymaker PETG.

## Parts List

Most parts are 3D printed.

Mechanical connections are made with either 3D printed friction clips or heat-set brass inserts and metal screws as needed.

The [Elecrow 7 inch display](https://www.amazon.com/dp/B08FMNDDSL) includes some mounting parts and speakers.

An optional [internal 20 mm (0.79 in) x 10 mm fan](https://www.amazon.com/dp/B07KS36L66) can be used. Note voltage requirements.

### Heat Set Inserts

For most of the enclosure, M3 inserts are used. There are 6 M2.5 screws used with the optional display mock-up, or 8 if you include the 2 unused positions.

Two M2 screws inserts are needed for the optional OLED frame.

Use an insert temperature of about 210 C. Insert gently and steadily. Avoid moving too slowly, as excessive heat can deform the plastic.

The [heat-set inserts](https://www.amazon.com/dp/B0FWWW8VP1) are the non-symmetric ones with an insertion lip (left) and have 4.1 mm holes:

<a href="./images/two_types_of_heat_set_inserts.jpg" target="_blank">two types of heat set inserts</a>

Screws are [M3 Philips Countersunk](https://www.amazon.com/dp/B0FZTYBXPY). Consider coordinating with enclosure color.

### ULX3S Enclosure Internal

- 4 each: M3 x D4 x L8,  internal tall posts
- 2 each: M3 x D4 x L4,  internal short plastic posts
- 4 each: M3 x D4 x L4,  bottom mounting plate holes; two different mounting plates depending on default Philips or hex drive screws.

### ULX3S to Elecrow Adapter Bracket

- 4 each: M3 x D4 x L4,  adapter hole for mounting ULX3S to display
- 2 each: M3 x D4 x L4,  adapter base plate spacer hole
- 1 each: M3 x D4 x L4,  adapter hole for securing USB strain relief cover

### Display Blank Mock-up

- 2 each: M2.5 x D3.5 x L4,  short HDMI display posts
- 4 each: M2.5 x D3.5 x L4,  RPi / ULX3S adapter posts

### ULX3S Enclosure External

- 2 each: M2 x D4 x L4,  OLED face frame screws

### Screws

Hex head screws generally work best. Most of the ones used for this project are flat head, flush screws.

- 4 each: M3 x 8 internal tall posts; longer screws up to 18 mm can be used.

- 2 each: M2 x 10 mm OLED face frame; exact length: 8 mm does not reach, 12 mm bottoms out.

TODO finish this list, see above

## Tools

- Soldering Iron
- Heat-set insertion tool
- Screwdriver (optional; recommend using hex screws instead)
- Hex wrenches:

| Thread | Socket Cap | Flat (Flush) |
| --- | --- | --- |
| M2 | 1.5 mm | 1.3 mm |
| M2.5 | 2.0 mm | 1.5 mm |
| M3 | 2.5 mm | 2.0 mm |

## 3D Printed Parts

In addition to the enclosure main body front and back, there are a variety of other parts that can optionally be used.

<a href="./images/enclosure_parts.png" target="_blank">part_button_set</a>

| Part | Description |
| ---- | --- |
| <a href="./images/part_ULX3S_To_RPi_Elecrow_Adapter.jpg" target="_blank">part_ULX3S To RPi Elecrow Adapter</a> | Adapter Mounting Bracket with internal USB restraint |
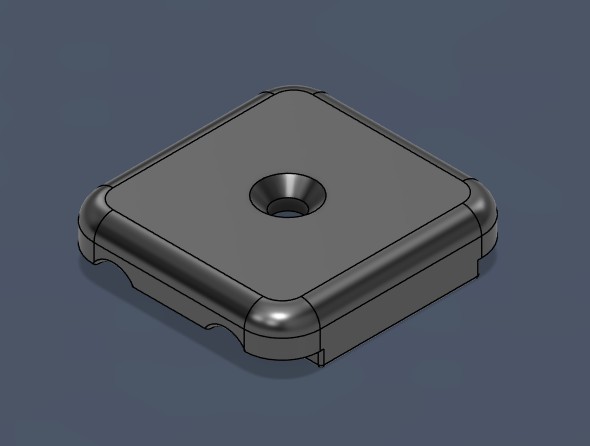
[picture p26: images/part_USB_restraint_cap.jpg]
part_ULX3S To RPi Elecrow Adapter
|  | Adapter Mounting Bracket USB Restraint Cap |
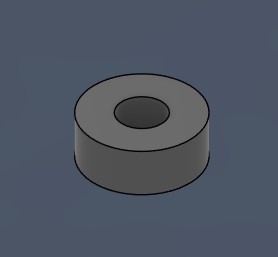
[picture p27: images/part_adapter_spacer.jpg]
part_ULX3S To RPi Elecrow Adapter
|  | Adapter Mounting Bracket Underside Spacers |
| <a href="./images/part_button_set.jpg" target="_blank">part_button_set</a> | Button Set (printed as a single connected piece for handling) |
| <a href="./images/part_display_bracket.jpg" target="_blank">part_display_bracket</a> | Display Bracket (2x); Philips default, see alternative Hex Head screw files. |
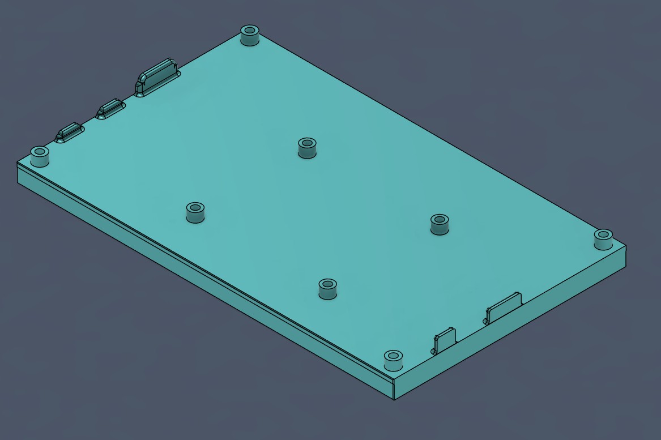
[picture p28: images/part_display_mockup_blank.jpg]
part_display_mockup_blank
|  | Display Mock-up Blank |
| <a href="./images/part_enclosure_ulx3s_side.jpg" target="_blank">part_enclosure_ulx3s_side</a> | Enclosure ULX3S Side |
| <a href="./images/part_enclosure_display_side.jpg" target="_blank">part_enclosure_display_side</a> | Enclosure Display Side |
| <a href="./images/part_face_spacer.jpg" target="_blank">part_face_spacer</a> | Face Spacer (4x) |
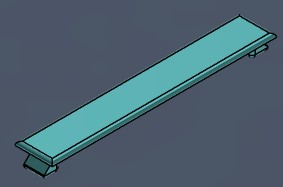
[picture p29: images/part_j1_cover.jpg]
part_j1_cover
|  | J1 Cover |
| <a href="./images/part_j2_cover.jpg" target="_blank">part_j2_cover</a> | J2 Cover |
| <a href="./images/part_j3_cover.jpg" target="_blank">part_j3_cover</a> | J3 Cover |
| <a href="./images/part_j4_cover.jpg" target="_blank">part_j4_cover</a> | J4 Cover |
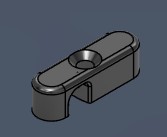
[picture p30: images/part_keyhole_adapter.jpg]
part_keyhole_adapter
|  | Keyhole Adapter |
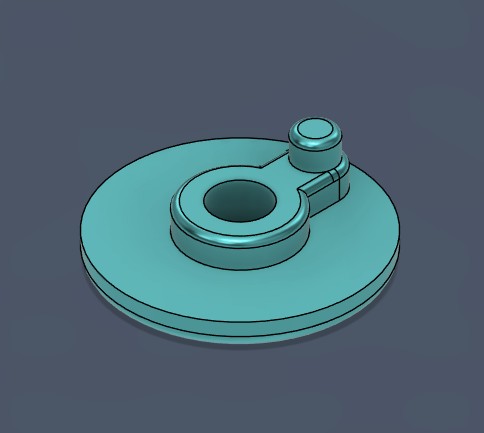
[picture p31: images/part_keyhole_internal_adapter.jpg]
part keyhole internal dapter
|  | Keyhole Internal Adapter Face Insert |
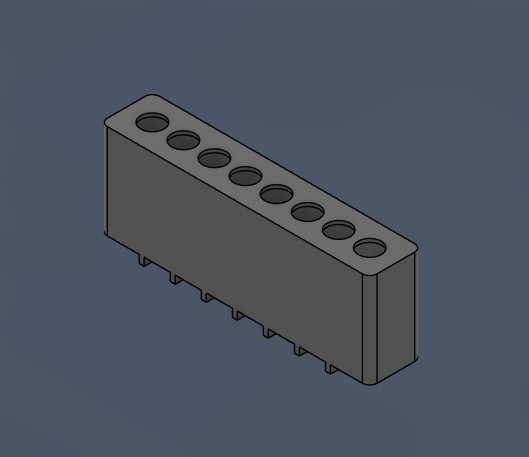
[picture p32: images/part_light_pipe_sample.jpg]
part light pipe sample
|  | Light Pipe Sample (not part of the assembly; used to test optic fit)|
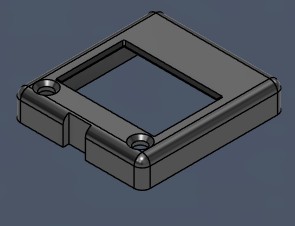
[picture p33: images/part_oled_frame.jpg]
part_oled_frame
|  | OLED Frame |
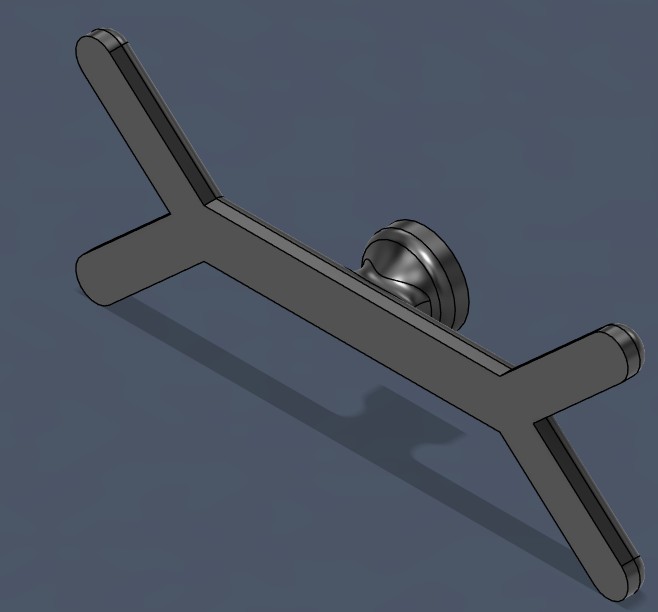
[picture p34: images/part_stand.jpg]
part_stand
|  | Stand |
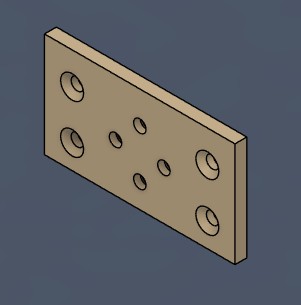
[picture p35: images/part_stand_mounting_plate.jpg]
part_stand_mounting_plate
|  | Stand Mounting Plate; Philips default, see alternative Hex Head screw files |
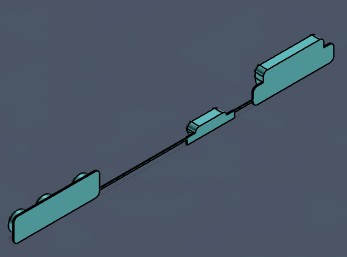
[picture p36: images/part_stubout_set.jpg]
part_stubout_set
|  | Stub-out Set |

## Instructions

Begin by inspecting all plastic parts that may have been printed with minor imperfections, strings, or brims that need to be trimmed.

If a more polished enclosure is desired, see the ["Spray Paint Finish Process: Fantastic Surface technique for prototype Models & Mock ups" on YouTube](https://youtu.be/0Z-cBnH79J4):

## Solder Desired Headers to ULX3S

The ULX3S side of the enclosure is designed for very exacting mechanical fit. Ensure all soldered headers are reasonably perpendicular to the ULX3S board.
This is particularly important for the single-row connectors such as the `OLED1` connector.

There are optional headers that may need to be soldered to the ULX3S board:

- `OLED` for use with the SSD-1331 display on the opposite side of the enclosure
- 40-pin `J1` and `J2` for GPIO, power and ground
- J3 (`GND` and WIFI_OFF: `ESP32 EN`)
- J4 JTAG 6 pin header: `3v3`, `GND`, `TDO`, `TDI`, `TCK`, `TMS`.
- J5 (VJ1) `+3v3` and `+2v5`, pin 2 is `2V5_3V3` (note: inaccessible from front panel when using the OLED frame)

Note: The fan connector on the Elecrow 7 inch display collides with pins on ULX3S J2 when using a block header. Trim the plastic housing and/or the J2 header pins on the underside of the board.

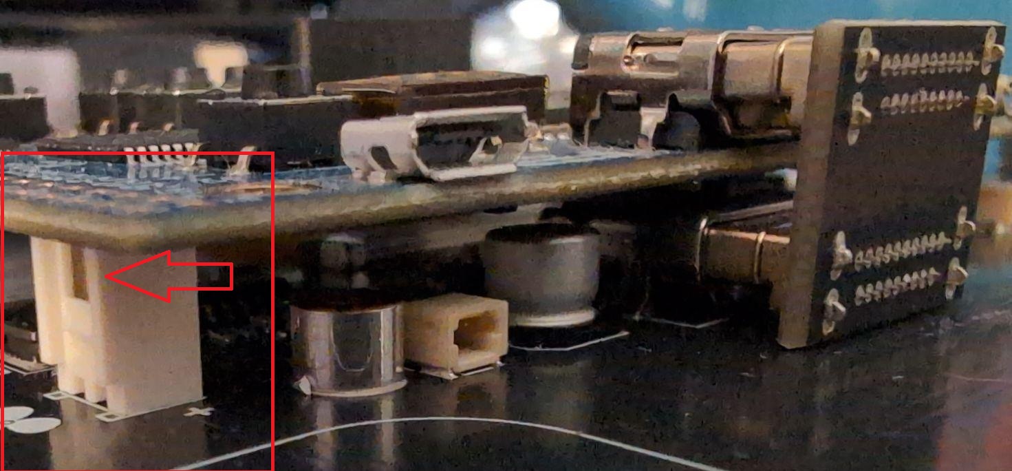
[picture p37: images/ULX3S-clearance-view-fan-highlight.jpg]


## Install Heat-Set Inserts

### Install Brass Inserts on Display Side

Install 4 of the M3 brass heat-set inserts on the tall enclosure posts.

CAUTION: These are the most important mechanical connections, holding the enclosure together. Do not apply too much heat that may deform the posts.

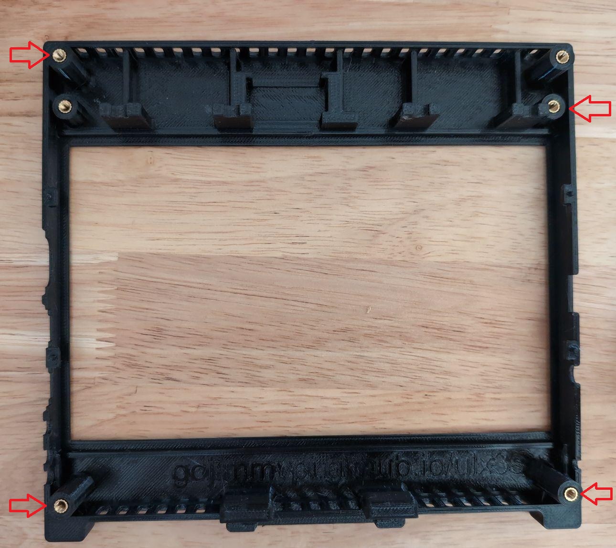
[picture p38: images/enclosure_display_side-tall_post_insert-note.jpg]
enclosure_display_side


Install M3 brass inserts on each of the two shorter bracket posts near the top of the display.

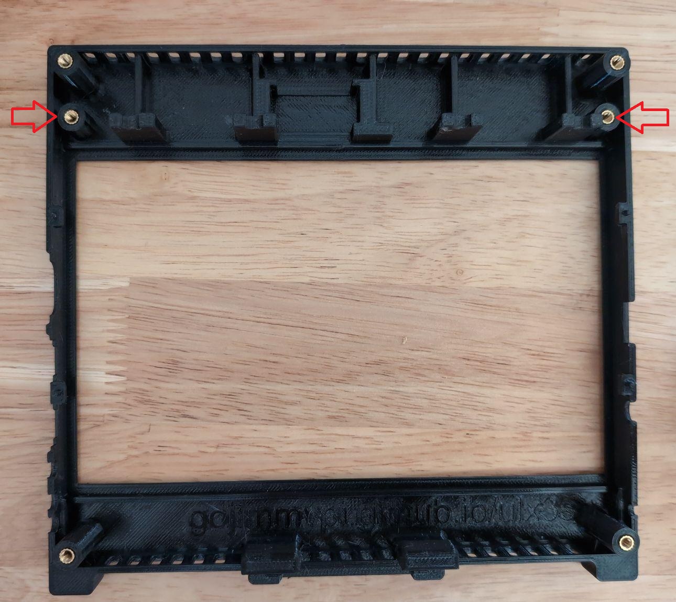
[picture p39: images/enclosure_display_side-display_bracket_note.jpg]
enclosure_display_side


Note that the display brackets are used only on the top two posts for vertical adjustment as needed.
All measurements are with respect to the PC board on the Elecrow display.
There is no reference for the position of the LCD display relative to the PC board,
so there's a bit of wiggle room built in, just in case.

The bottom of the display should rest against the stop on the side panel:

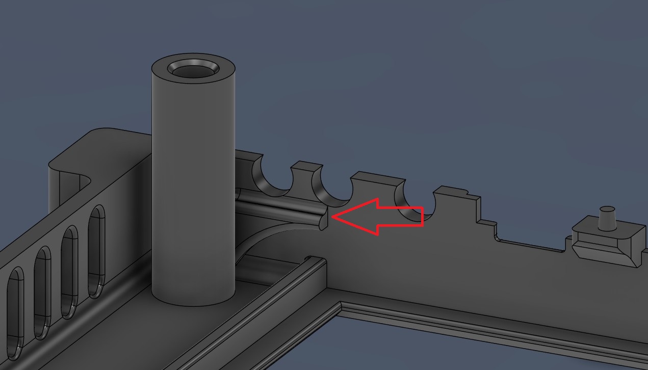
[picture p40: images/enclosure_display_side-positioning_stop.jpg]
enclosure_display_side


Double-check that the USB, HDMI, and audio holes align properly.

All 4 display posts are also secured internally from above via these posts on the ULX3S side:

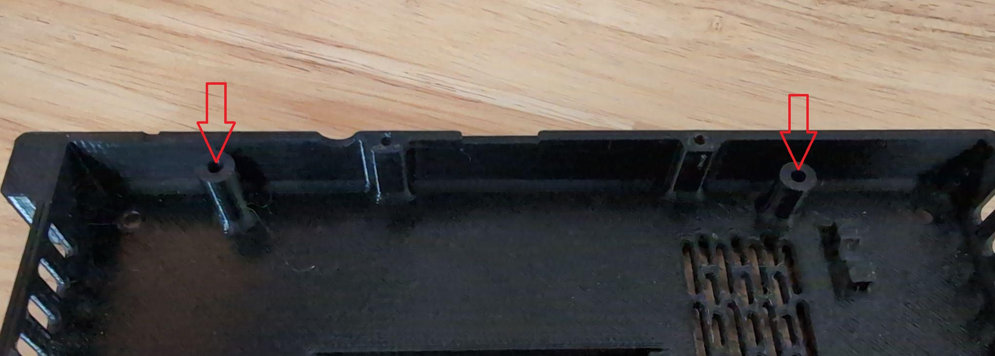
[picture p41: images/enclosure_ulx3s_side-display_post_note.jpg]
enclosure_display_side


Ensure that appropriate flush screws are used for the display mounting brackets and no internal wires are placed over the display
mounting posts. Otherwise, the enclosure sides may not properly fit.

There are two different mounting plates: the default if for a Philips screw with a 1.3 mm chamfer. There are alternative hex screw files for hex drive screws with a 2 mm chamfer. See files with `(Hex Head)` name suffix.

The Philips hole with a hex screw results in a nearly 1 mm clearance problem:

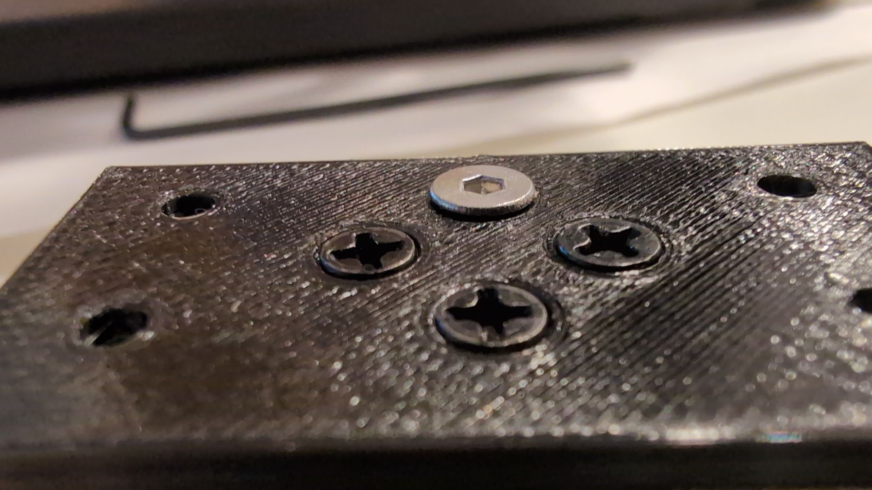
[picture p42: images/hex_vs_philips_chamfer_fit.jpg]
hex vs philips chamfer fit


Setting all the holes to the 2 mm hex size results in Philips screws being recessed too far.

Choose a mounting plate for the screws used, then install the 4 bottom mounting plate M3 heat inserts in the base of the enclosure display side:

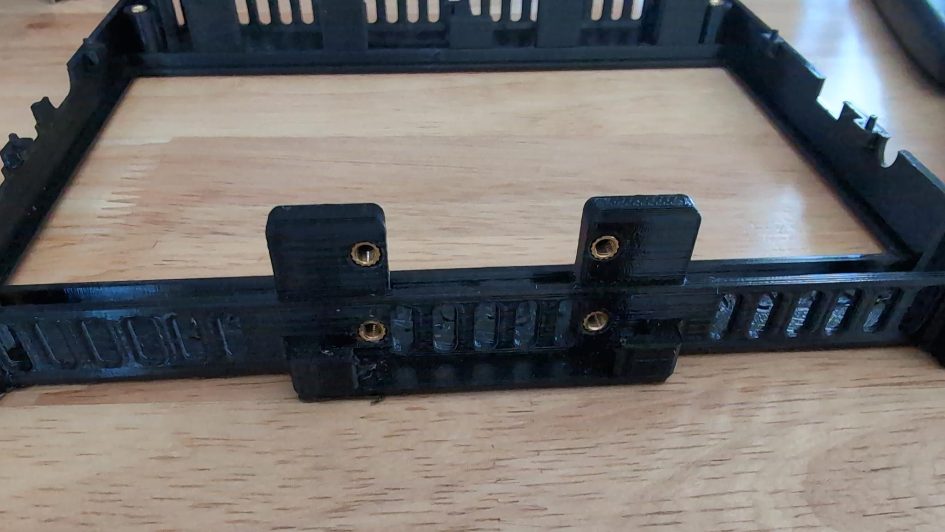
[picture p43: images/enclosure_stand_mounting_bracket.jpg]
enclosure_stand_mounting_bracket


### Install Brass OLED Frame Mounting Screw Inserts on ULX3S Face Side

The OLED display side uses smaller M2 screws to secure the SSD 1331 PCB and OLED face frame to the enclosure.

When using the optional [OLED 1331 display](https://www.amazon.com/dp/B0711RKXB5), install two `M2x4x3.5` brass inserts in the front panel.

Be sure to support the enclosure from below to ensure not deforming or cracking the plastic face, particularly if not using a heat set insert tool.

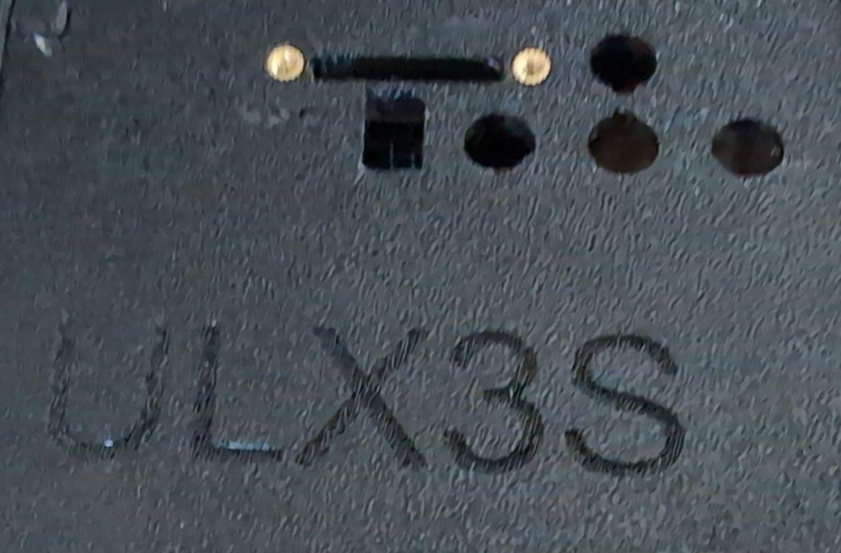
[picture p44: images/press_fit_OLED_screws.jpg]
press_fit_OLED_screws


Only install the inserts. Do not mount the OLED screen at this time to allow the display to lay flat later during assembly.

### Light Pipe Block (Optional)

There are 8 general purpose LEDs and 3 system LEDs on the ULX3S that can be better illuminated on the enclosure face with [2 mm (0.08 inch) fiber optic light pipes](https://www.amazon.com/dp/B0BLH9TSHV).

When using 2 mm fiber optic pipes, the fit is rather tight in the holes due to dimensional constraints when using a 0.4 mm 3D printer nozzle: 2.54 mm between holes.

The light pipe blocks have holes positioned directly over the LEDs on the ULX3S board. To improve brightness on the enclosure face, optional fiber optic filament can be inserted into each hole.

Do not precut the fiber optic filament line for the light pipes unless you have a means for accurate sizing and inserting.

Consider polishing the cut end before inserting. Deformation on the end may make insertion more difficult.
A nicely polished end will also transmit light more effectively. Here's a close-up view of the fiber light tube that was cut with diagonal snips:

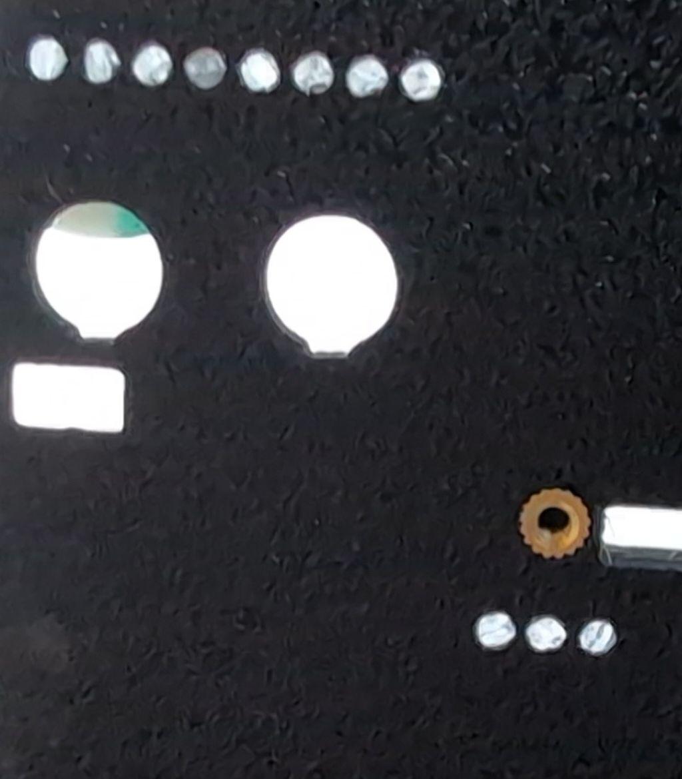
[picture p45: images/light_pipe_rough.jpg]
light_pipe_rough


The holes for the filament are purposely snug to retain the light pipe with no glue or other mechanical connectors.

Clean out each hole using a long M2 screw (10 mm or longer) to remove any debris or print artifacts.

Note that there's a small lip at the face to help retain the light pipe from being pushed too far.  Excessive force can damage this and push the filament out.

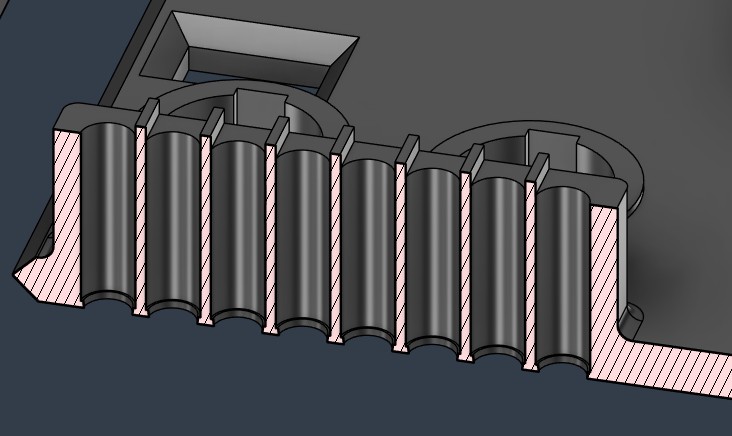
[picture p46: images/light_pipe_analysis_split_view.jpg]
rendered analysis view in Fusion showing split light pipe block


Ensure the ULX3S side is firmly placed face-down with no obstructions.

Firmly insert a length of fiber optic filament into each of the 8 LED holes and the 3 diagnostic LEDs.

After each filament is inserted, check the face to ensure the filament nearly reaches the face surface for best results.

Cut the filament, then push the remainder to be flush with the light block _below the level of the light fences_.
Note the light fences between each hole in the light block:

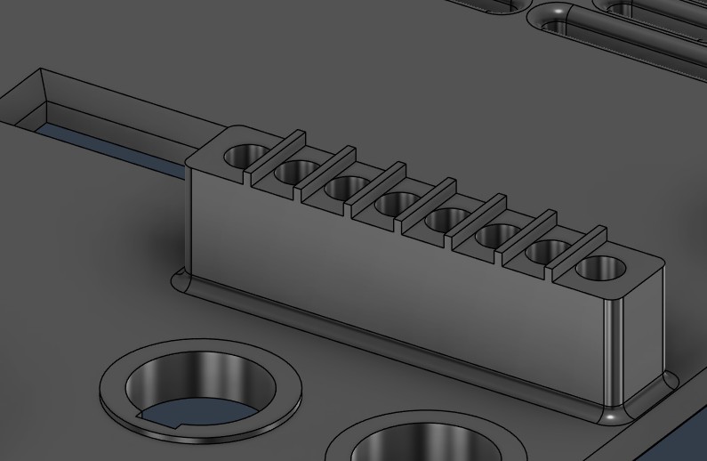
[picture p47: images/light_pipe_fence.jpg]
light pipe fence rendering


These fences are designed to limit any cross-LED light contamination to a neighboring hole.
The light pipe _block_ should reach the _level of the LEDs_ on the ULX3S board when assembled.
The fences extend _beyond_ this and are positioned _between_ each LED. The fence nearly touches the PC board.

Worst case, use fine sandpaper to polish everything down to the light pipe block.
Removing the fences typically has minimal impact given the brightness of the LEDs but is not very pretty:

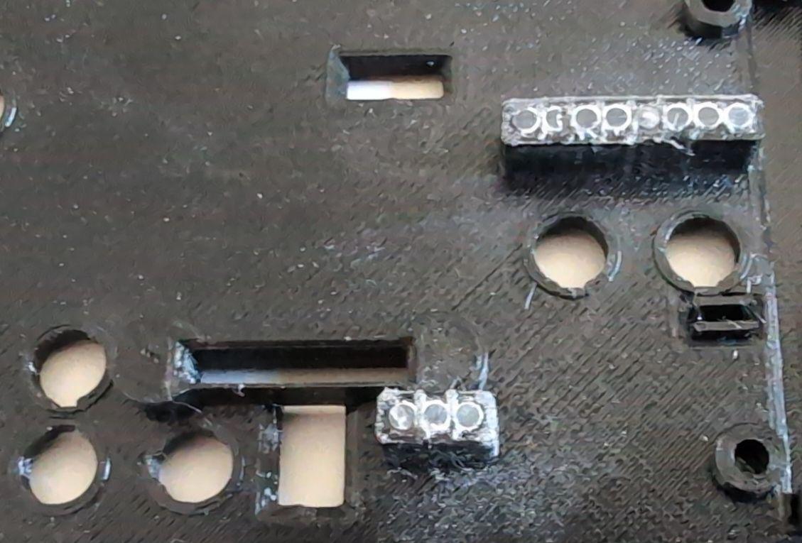
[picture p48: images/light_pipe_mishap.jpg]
light_pipe_mishap


If the light pipe fiber optic filaments are too long, the enclosure face will have a slight bulge and the F1 and F2 buttons will not extend as far as the other buttons.
This condition puts strain on the PC board, which may shorten its life.

### HDMI Stub-out

When using the internal HDMI connector, the external HDMI and display touch USB connectors should be stubbed out to ensure they are not used concurrently (see documentation).

### Keyhole Adapter

The ULX3S side of the enclosure includes a keyhole in case you have a project to hang on the wall.

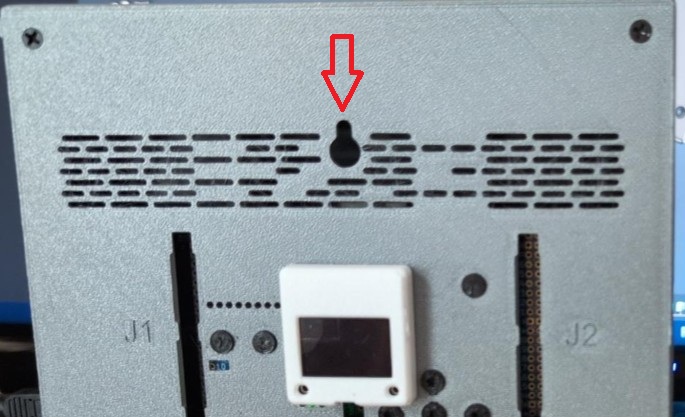
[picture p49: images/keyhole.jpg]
keyhole


If using the keyhole-to-lanyard adapter, install the one brass insert in the rear (internal) keyhole internal adapter (circular disc).

Only install the inserts. Do not mount the keyhole screen at this time to allow the display to lay flat during assembly.

CAUTION: The intern HDMI connector is located nearby. Excessively long screws may collide, particularly when using the ribbon-cable connector.

### Display Blank (optional)

If using the blank panel instead of an HDMI display, place the 4 mounting post inserts for the ULX3S and the 2 display posts used for the mounting brackets. There are 2 display mounting post holes included in the mock-up to match the real display but are not used.

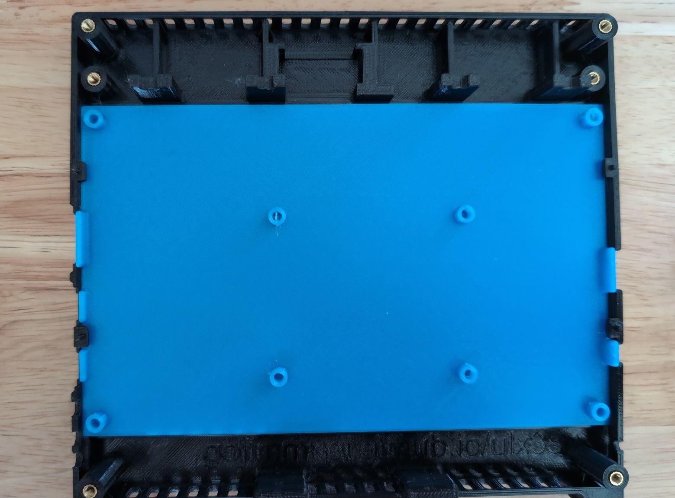
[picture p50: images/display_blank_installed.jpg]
display_blank_installed


Due to the recessed panel thickness on the left HDMI / USB side, the enclosure alignment post clips are slightly wider than those on the right.

First insert the left side of the HDMI display observing the snap-clips on each side of the enclosure.

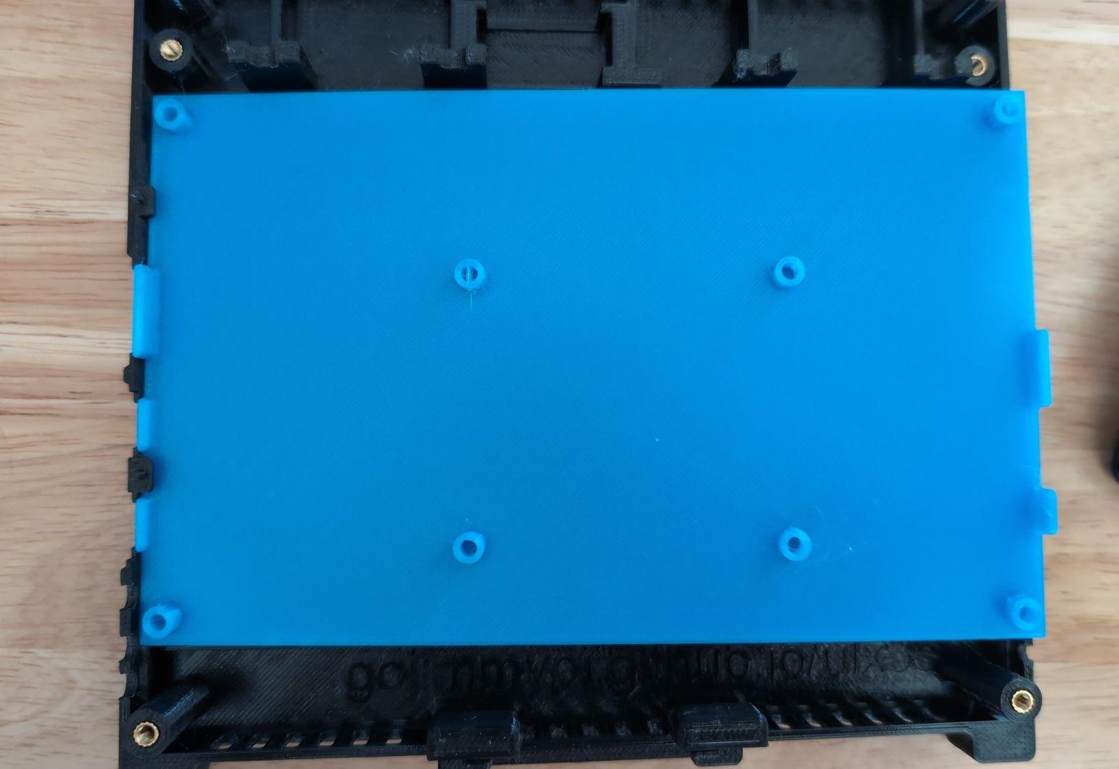
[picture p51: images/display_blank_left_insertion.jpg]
display_blank_left_insertion


The left (HDMI/USB) display enclosure side has slightly thicker snap-in posts. First insert the display on the left.

Ensure the display is snug and resting underneath the snap-in guides.

Lower and press the right side into place while gently pulling the right side panel out. Snap the display into place.
Note the connectors that are stubbed out as part of the display mock-up.

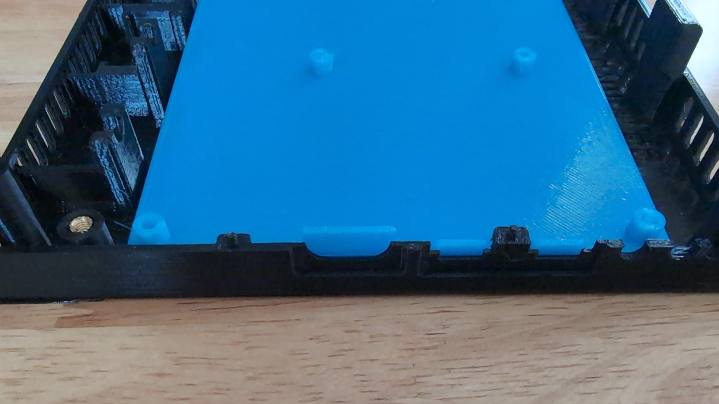
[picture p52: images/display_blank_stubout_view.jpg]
display_blank_stubout_view


## Install Display Assembly into Enclosure

Due to the recessed panel thickness on the left HDMI / USB side, the alignment post clips are slightly larger than those on the right.

First insert the left side of the HDMI display observing the snap-clips on each side of the enclosure.

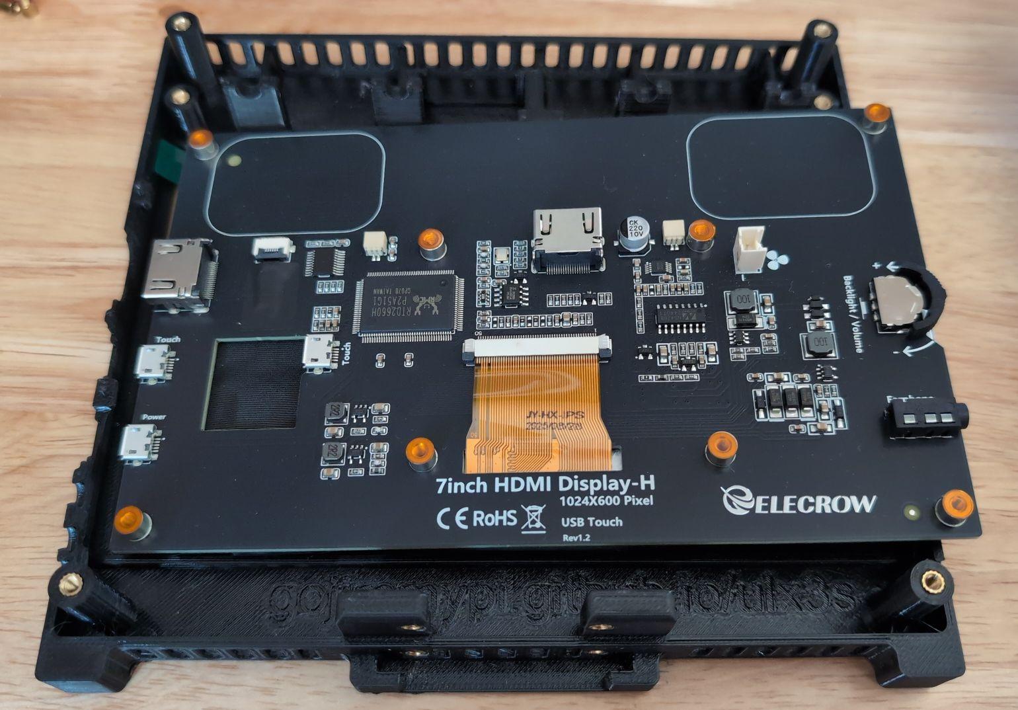
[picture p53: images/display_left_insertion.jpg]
display_left_insertion


Lower the right side into place while gently pulling the side panel out and snap the display into place.

Remove orange kapton tape covering top 2 display mounting post M2.5 holes (if present). The bottom 2 posts are not used.

## Mount ULX3S to Display (or Mock-up)

These steps apply to either the HDMI display, or the optional mock-up (above) which has mounting posts in the same locations.

### Install ULX3S to Raspberry Pi Mounting Adapter

The Elecrow display was designed for the Raspberry Pi, not the ULX3S. As such, the display mounting posts do not line up with the holes on the ULX3S:

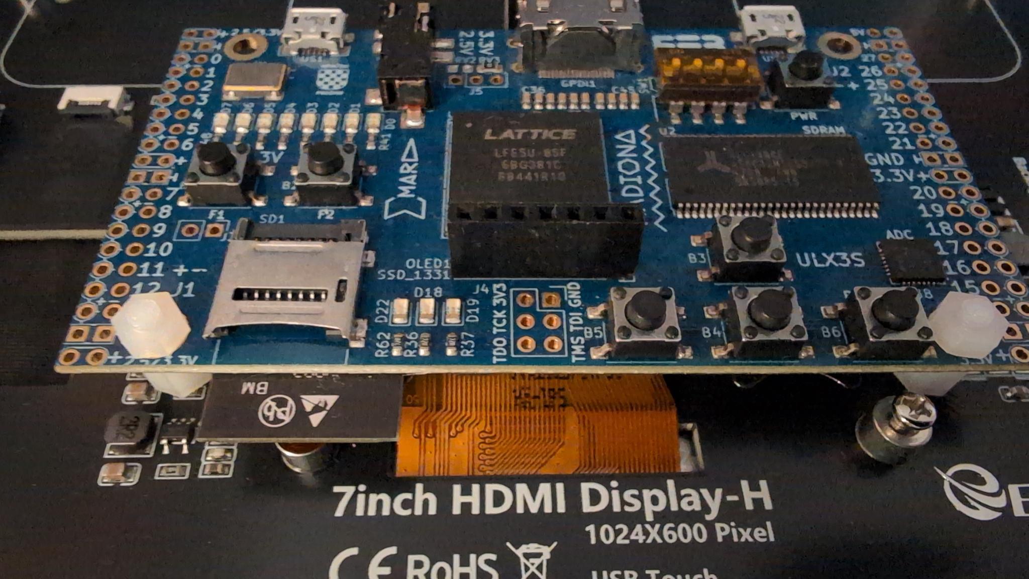
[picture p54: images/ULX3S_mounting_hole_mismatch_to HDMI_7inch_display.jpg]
display_blank_stubout_view


### Install Mounting Adapter Spacers

Ensure the 2 Mounting Adapter Spacers are installed underneath the Mounting Adapter first. These spacers should be the same height as the metal
spacers on the display. Do not confuse these two spacers with the 4 optional face spacers. The adapter spacers have a single printed layer on one end (no visible hole)
to protect the display from the metal insert. The side with the hole also has no chamfer, as the screw enters from the adapter side.

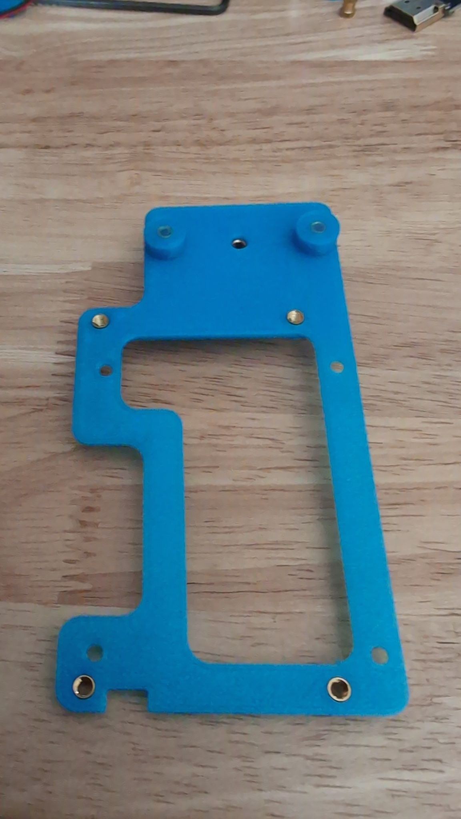
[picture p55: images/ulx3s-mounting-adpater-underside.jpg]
ulx3s mounting adpater underside


Place the Mounting Adapter over the 4 Raspberry Pi positioned M2.5 mounting posts.

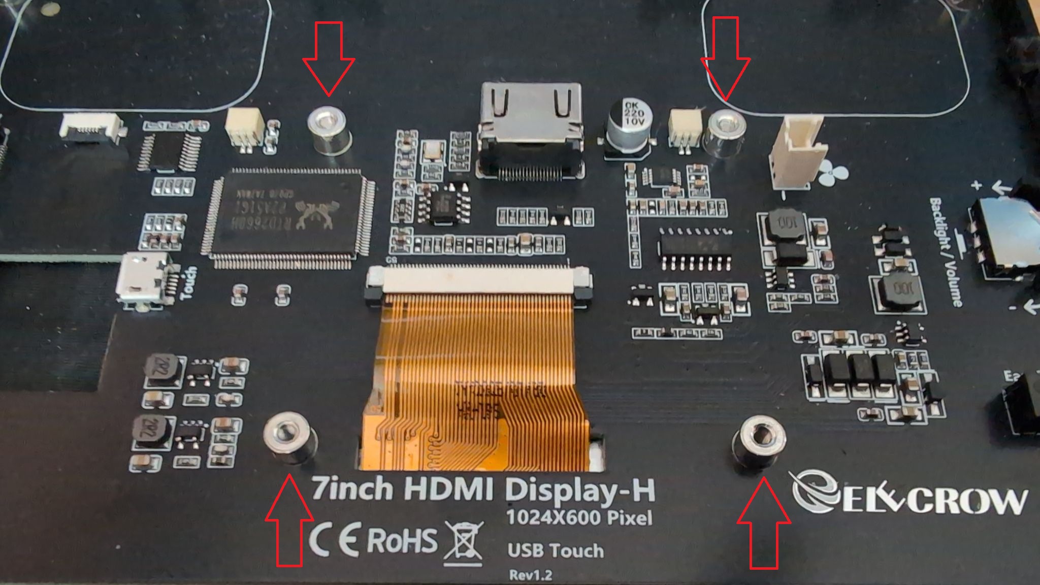
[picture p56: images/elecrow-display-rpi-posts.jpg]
elecrow display rpi posts


Secure the adapter to the display with either the 4 screws that should have been included with the display, or other M2.5 x 4 mm screws.

Beware of components on the bottom side of the ULX3S that may collide with thick pan head screws or spacers.

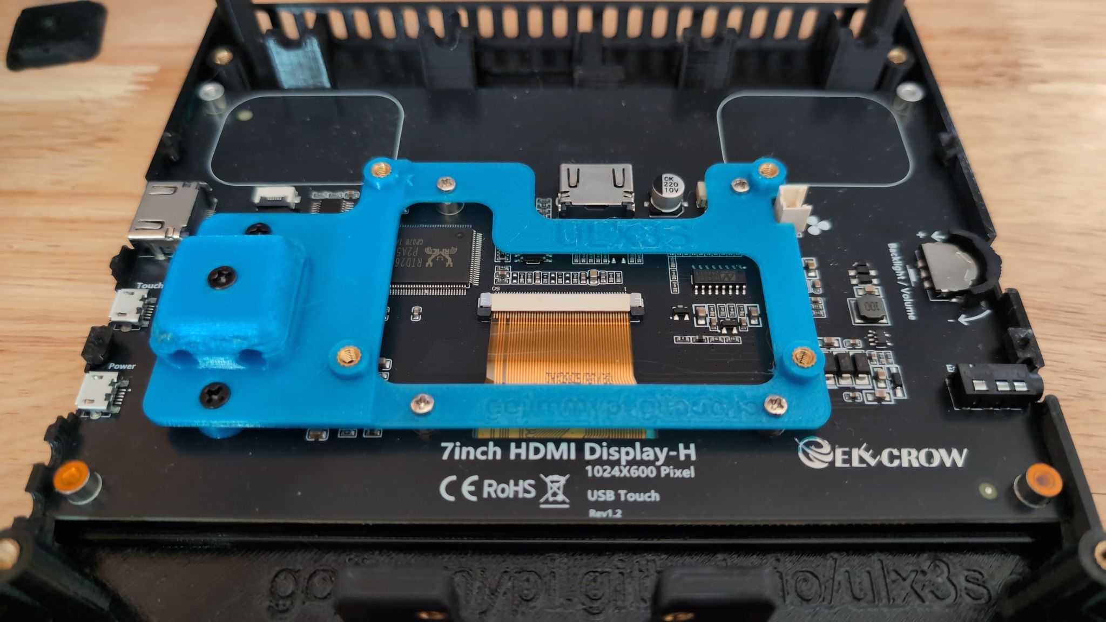
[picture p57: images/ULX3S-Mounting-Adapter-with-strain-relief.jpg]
ULX3S Mounting Adapter with strain relief


Before proceeding, ensure the spacers are installed under the strain relief as described above.

Confirm that no display components will be crushed under the strain relief. This is unlikely, but there's no guarantee
that a future version of the display won't relocate some components.

### Connect the A1-A1 HDMI

When using the A1-A1 HDMI PC Board adapter, there's very little room between the mounting posts
and the ULX3S, particularly since there are components on both sides of the board.

As the HDMI display was designed to be used with the Raspberry Pi, use the custom adapter:

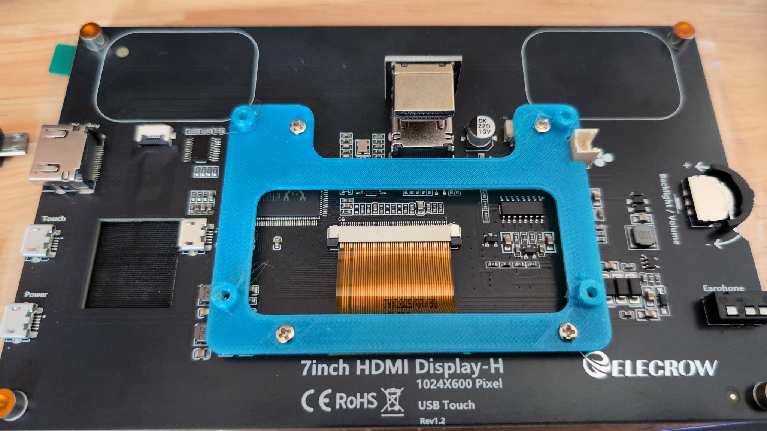
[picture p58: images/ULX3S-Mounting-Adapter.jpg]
ULX3S Mounting Adapter


After the adapter is secured to the display, attach the ULX3S:

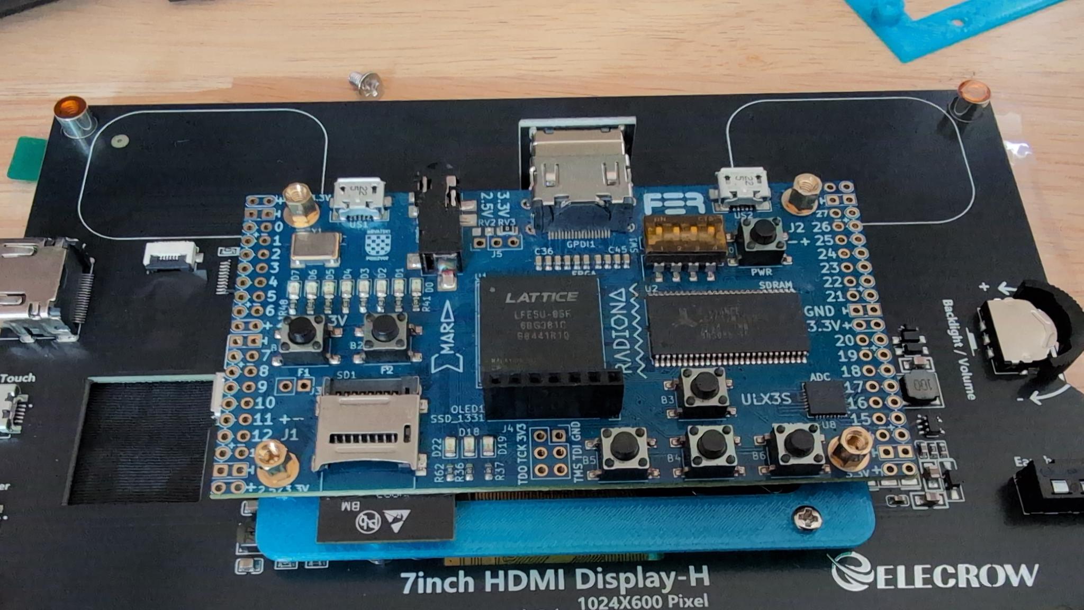
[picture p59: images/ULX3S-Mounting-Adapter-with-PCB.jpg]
ULX3S Mounting Adapter with PCB


Next, carefully insert the A1-A1 HDMI connector:

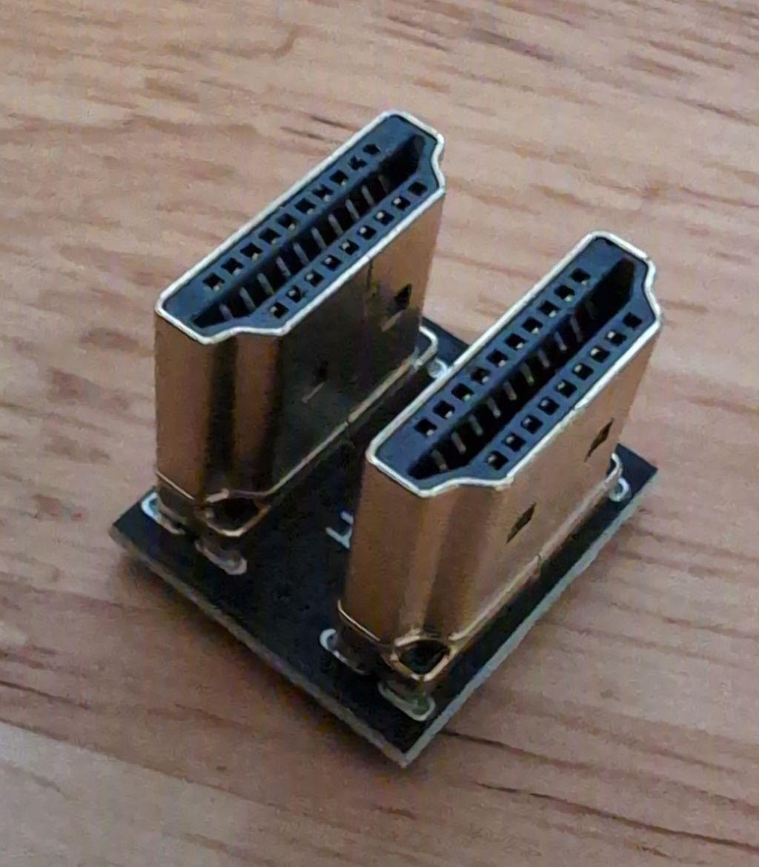
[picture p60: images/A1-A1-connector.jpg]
A1-A1 connector


Note the clearance between the ULX3S. There's an unfortunate placement of a white 2-pin header on the display directly below the J2 4 pin header.

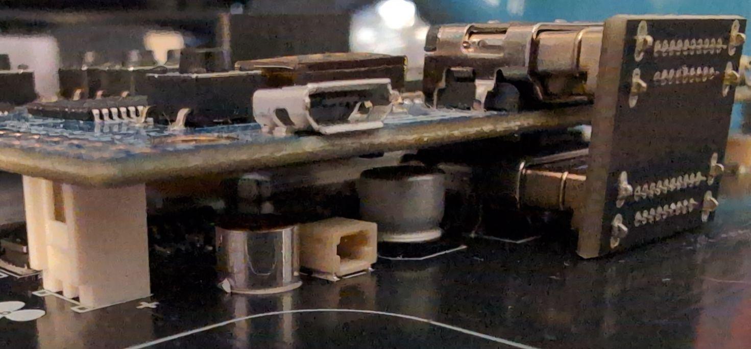
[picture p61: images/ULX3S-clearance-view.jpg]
ULX3S clearance view


If there is no A1-A1 adapter board available, there's enough room for a [short 10 cm A1-A1](https://www.amazon.com/dp/B0F1TBRSMZ/ref=dp_iou_view_item?ie=UTF8&psc=1).

Use caution with the Amazon links that redirect to similar, but _incompatible_ connectors when out of stock.
_There's only room for the A1-A1_, not any of the angled connectors (e.g. A1-A2, A1-A3). The reversed position connector is not recommended as the cable would need to be twisted (e.g. A1-C1).

For reference, see the A1 options for HDMI cables:

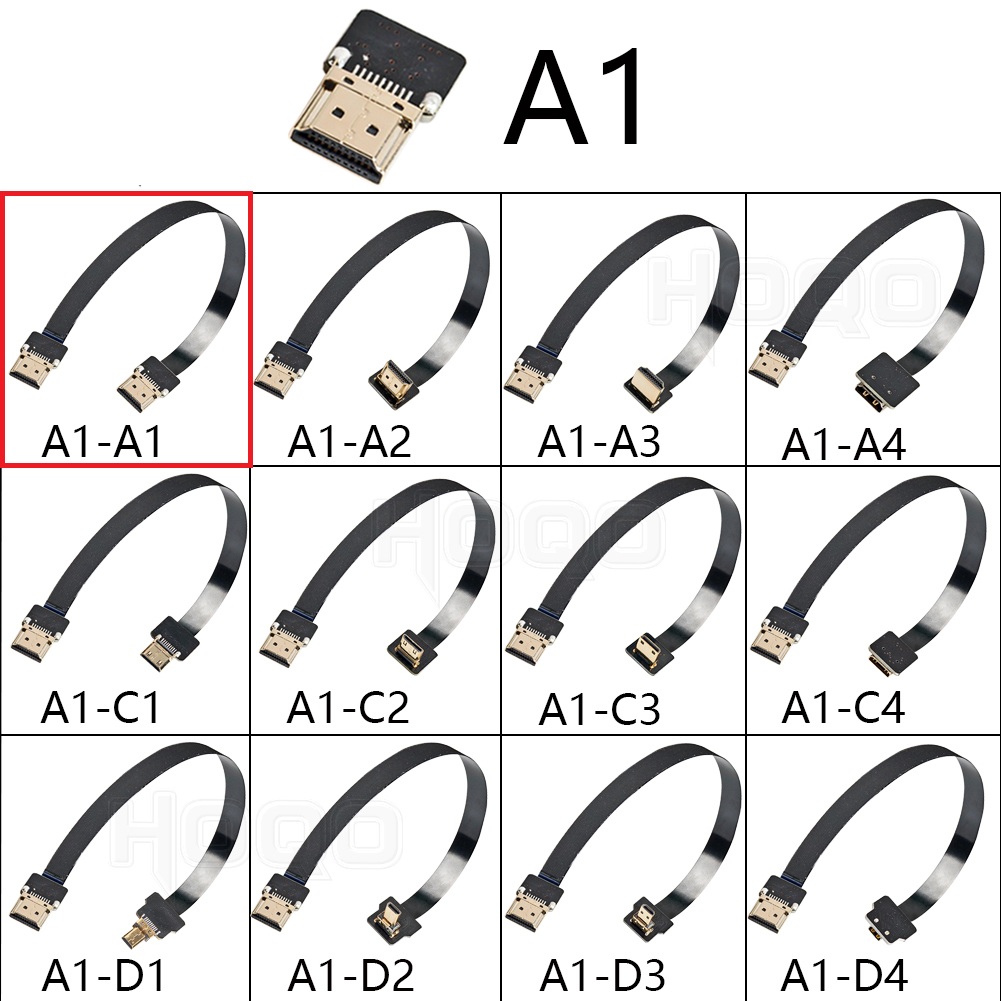
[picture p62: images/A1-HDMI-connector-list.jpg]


## Place Buttons in ULX3S side

Ensure the holes and buttons are clear of any debris, print strings, or other obstructions.

There is a small connecting strip (roadway) that keeps all buttons together during printing.
This ensures the model is treated as a single body during printing and helps prevent parts from being lost during handling.

When printed with PETG, the roadway connections between buttons should be flexible enough to no interfere
with button operation.

Lay the back of the enclosure (ULX3S side) face down and carefully identify and place each button in the respective holes.

Note that there are some orientation posts on the button shafts to ensure specific alignment and prevent rotation.

There are two button roadway clips built into the enclosure face. Snap the roadways in place as shown:

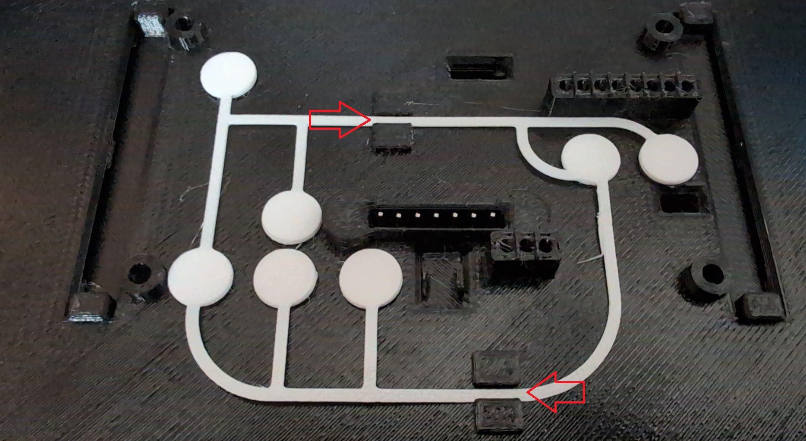
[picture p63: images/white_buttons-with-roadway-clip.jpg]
white buttons with roadway clip


The roadway clips are only intended to help keep the button set from falling out when handling the enclosure.

Before assembly, ensure each of the buttons moves freely in the respective enclosure face hole.
The tactile button feedback offers little force to push the button. If there's any resistance,
resolve before proceeding. The holes should be accurately sized.
A little buff of sandpaper will typically resolve any print-time imperfections.

## Place the HDMI Stub-out

** WARNING **  Do not attempt to use the external HDMI connector when display connected also to the ULX3S internally.

To ensure the second display HDMI connector is not inadvertently used, install the HDMI stub-out panel to block access to the external HDMI connector.

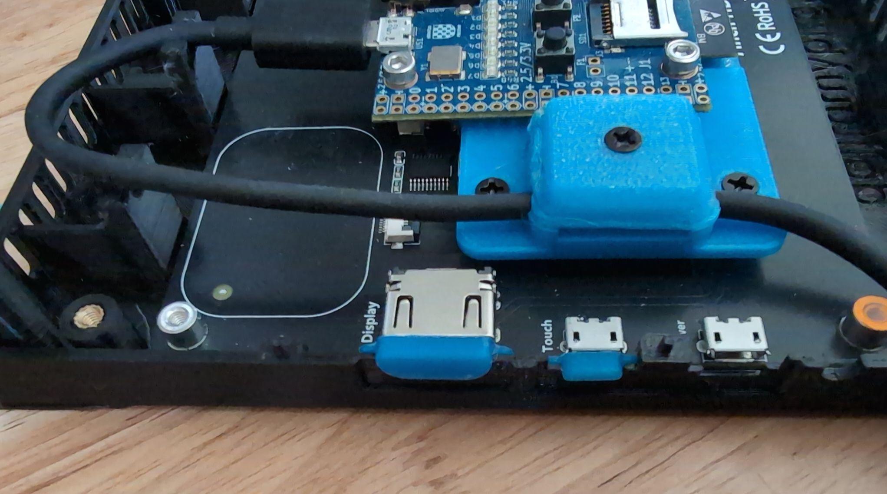
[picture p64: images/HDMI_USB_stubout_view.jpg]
HDMI_USB_stubout_view


Note there are _two_ Elecrow display USB Micro-B connectors: `Touch` and `Power`. Pick _one_, stub out the other. Typically the `Touch` will be stubbed out unless
there's some logic and/or electrical connections to feed back the touch signals to the ULX3S or ESP32 for processing. The HDMI and first adjacent USB connector can remain connected as printed.

Unless some other means of power the display is implemented, at least one of the display USB connectors must be used.

As the HDMI and USB stub-outs are very small, consider a dab of glue to hold them in place.

## Route Internal USB Cable(s)

Unless the FPGA is programmed to retain an HDL binary image, a USB cable will be needed for (re-)programming after power down.

The connector to the _left_ (when viewed from the FPGA side and the HDMI connector at the top), `US1`, is the one for FPGA programming:

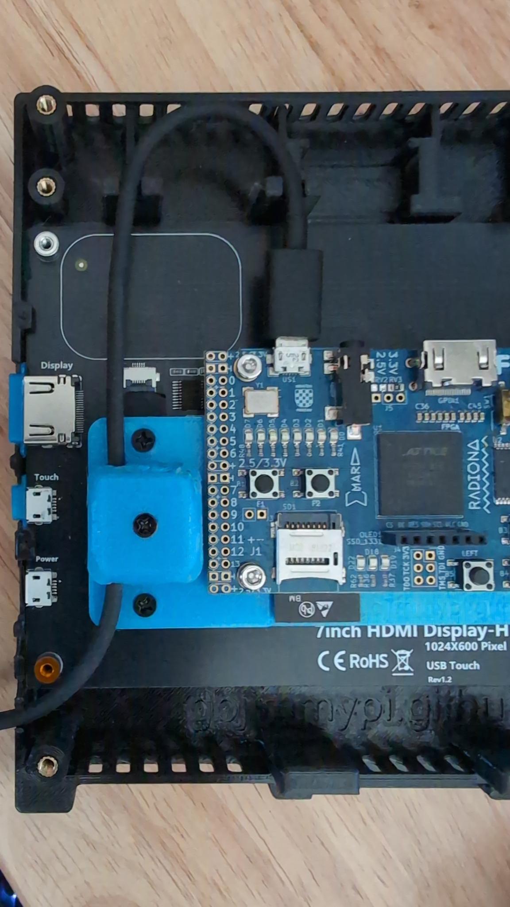
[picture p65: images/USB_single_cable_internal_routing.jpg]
USB_single_cable_internal_routing


If `US2` (e.g. USB HID, keyboard, USB host) is also desired to be accessible once the display is assembled, route it as well.

<a href="./images/USB_dual_cable_internal_routing.jpg" target="_blank">USB_dual_cable_internal_routing</a>

Note that a USB controller will need to be implemented in the FPGA when using `US2`.

## Internal Fan

If planning to use an internal fan, ensure the USB cables are routed appropriately.

<a href="./images/fan_with_wire.jpg" target="_blank">fan and wire</a>

The bottom two mounting posts for the display are not used. **Note:** The ULX3S side includes internal support posts that align with these positions. Do not obstruct them.

## Assemble Mounting Post Stand (optional)

When 3D printed with a brim, ensure any excess material is removed from the ULX3S side.
The plate should be snug but not too tight.

Secure the mounting plate to the stand. Note one side of the plate has a chamfered hole to allow the screw to be flush with the surface:

<a href="./images/stand_top_screws.jpg" target="_blank">stand_top_screws</a>

Install all 4 screws before gradually tightening each in succession. Do not over-tighten to the point of deforming the plastic.

The stand can be left attached to the _front_ display half when opening the enclosure.

Slide the stand assembly into the enclosure slot. allowing the stand feet to hang over the work surface:

<a href="./images/stand_attach.jpg" target="_blank">stand_attach</a>

Secure the stand base plate to the display side of the enclosure only, using the two M3 screws near the work surface. Do not install the other base plate screws at this time.

<a href="./images/stand_attachment.jpg" target="_blank">stand_attachment</a>

## Assemble Lanyard Keyhole Adapter (optional)

There are two parts to the keyhole lanyard adapter:

- Internal Keyhole Face Insert and stress relief disc
- Keyhole External Adapter to hold metal key-chain ring
- Optional 3D-printed ring

One M3 x 4D x 4L heat set insert is needed to secure the two parts together:

<a href="./images/keyhole_adapter.jpg" target="_blank">keyhole internal and external adapter</a>

Align the disc with keyhole extrusion on the inside of the case, install a ring if desired, and then screw the external keyhole adapter using an M3 x 10 mm screw.

<a href="./images/ulx3s_keyhole_adpater_badge.jpg" target="_blank">keyhole internal and external adapter with hackaday lanyard</a>

Keep in mind the display is relatively heavy for a 3D printed part. Care should be taken to ensure too much stress is not applied to the lanyard.

## Attach OLED Frame with SSD 1331 Display (Optional)

Only two screws are used to secure the OLED frame to the enclosure. Note that the frame covers the
`J5` connector.

There are two tabs at the end opposite the OLED Face frame notch. Insert the display at an angle there first:

<a href="./images/oled_insert-this-side-first.jpg" target="_blank">oled insert this side first</a>

Next, gently press the display into the face frame. The 7 pin header should be flush with the frame:

<a href="./images/oled_installed_faceframe.jpg" target="_blank">oled installed in faceframe</a>

Note the alignment of the display pins into the enclosure. (assumes header has been installed: see prior instructions)

<a href="./images/oled_pins_ready.jpg" target="_blank">oled pins ready to insert into faceframe</a>

Once plugged in, attach the OLED Face Frame to the enclosure with 2 screws: M2 x 10 mm

<a href="./images/oled_faceframe_screws.jpg" target="_blank">oled faceframe screws</a>

## Attach Front Display and Rear ULX3S Sides of Enclosure Together

As the OLED frame (see prior step) extends nearly 7 mm from the face of the enclosure, consider
whether spacers should be used in each of the corners of the face. When used in a lay-flat configuration
with the HDMI side facing up, the spacers stabilize the enclosure on the workbench.

Use 4 of the M3 x 4 mm screws: one in each corner of the ULX3S face to
secure the two sides of the enclosure together. Ensure no internal obstructions (e.g., wires over mounting posts or fan placement issues) before closing the enclosure.

Screws up to M3 x 20 mm can be used, allowing the flexibility of the optional OLED frame face spacers.

## Problems, Questions, Comments?

- Open a [GitHub issue](https://github.com/gojimmypi/ulx3s-elecrow-7inch-hdmi-enclosure/issues/new)

- Send me (gojimmypi) an email at gmail.

- Contact me on your favorite social media. See links at the top of [gojimmypi.github.io](https://gojimmypi.github.io/)

## Enjoy

Proceed to learn more about FPGA programming by visiting [Bruno Levy's "Learning FPGA, yosys, nextpnr, and RISC-V"](https://github.com/BrunoLevy/learn-fpga)
and reading FPGA Books such as [Kevin Hubbard's Mastering FPGA Chip Design](https://www.elektor.com/products/mastering-fpga-chip-design-e-book) (See the [extract](https://issuu.com/eimworld/docs/mastering_fpga_chip_design_extract_)).

There's a [Pull Request to add ULX3S HDMI resolutions for displays such as an Elecrow HDMI display](https://github.com/BrunoLevy/learn-fpga/pull/146).

See also [ulx3s.github.io/](https://ulx3s.github.io/) and reach out on [Discord](https://discord.com/channels/690209441953480758/1081150712479764530) with any questions.

## Did you make one?

I'd love to hear how it went! Good things, suggestions for improvements.

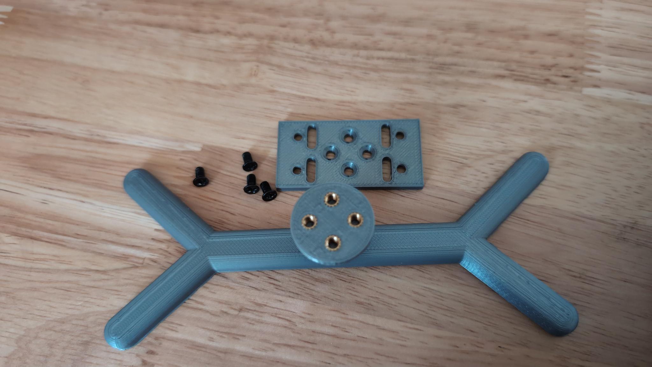
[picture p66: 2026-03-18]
images/standa_assembly_top.jpg

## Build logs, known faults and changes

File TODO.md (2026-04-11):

# TODO

- [ ] Ensure lay-flat with stand attached.
- [ ] Ensure lay-flay stand: smaller legs and/or longer face feet.
- [ ] Light Pipe install and tool
- [ ] Pre-drill all but 1 mm of display posts
- [ ] Consider though-holes on posts for center-of-gravity
- [ ] Create full-face stub-out for ULX side (non-developer version, only using display)
- [ ] Improve mounting plate screws and fillets
- [ ] Add stabilizing bolt hole in stand
- [ ] Extend post tube to ULX3S board surface at mounting holes
- [ ] Ensure chamfer is deep enough for flat hex head screws; currently only Philips are flush. Issue only with mounting plate. See `M3_Countersink_Chamfer` dimension. A value of 1.3 mm works for Philips, but hex heads protrude a bit. Edit to 2.0 mm. Added second set of files for Hex Head.
- [ ] Reposition stand mounting screws for symmetry. Recent change extending plate to face broke symmetry.
- [ ] Consider recess for volume knob
- [ ] Add knurl to face spacers to act as disassembly knobs
- [ ] Create optional chamfer spacers for ULX3S mounting Philips countersunk screws
- [ ] Increase chamfer depth on mounting plate screw holes
- [ ] Create or revise stand to fit _inside_ the enclosure for storage
- [ ] Adjust J3 and J4 that break using brittle non-Prusament filament

## Adapter

- [ ] Add 3rd cable to strain relief
- [ ] Add alternate version for thicker 4 mm USB cables

## Display Blank

- [ ] Increase diameter and measure M2 post sizes
- [ ] Add speaker and other interesting references
- [ ] Recheck stub-outs

## Other

- [ ] Create practice heat set install block
- [ ] Improve USB restrain cap & allow for multiple cable sizes
- [ ] OLED connector blank
- [ ] Buttons blank
- [ ] Full panel blank
- [ ] Recheck (Display_Offset_Post_Height - Display_Post_Height) =  (4)

## Done

- [x] Display has tight fit left-right. Adjusted Bezel_Fit from 0.1 to 0.2, then reverted to 0.1 after chamfer to fillet change
- [x] ULX3S side is too far from PCB
- [x] Display audio input hold is misaligned, 43.16 is 2mm too far; No, it is adjustable!
- [x] Volume Control hole misaligned, no it is adjustable@!
- [x] USB internal USB strain relief posts both misaligned. Fixed, but recheck.
- [x] HDMI alignment can be improved. HDMI position incresed from 34 to 35 mm
- [x] Add fillet to HDMI hole/ (Skipped)
- [x] Move ULX3S USB cable exit holes
- [x] Consider HDMI cap? (Maybe later)
- [x] Loosen Button Diameter. Adjusted to Button_Post_Diameter + 0.3 mm
- [x] Remove display clip chamfer. Suppressed, replaces with 0.5 fillet.
- [x] Add display positioning bracket
- [x] Resize Display Offset Posts (2 only! or all with USB strain relief after moving exit?)
- [x] Keyhole Hanger
- [x] OLED mounting holes
- [x] Fan
- [x] Mounting pin hole depth
- [x] Confirm all header fit
- [x] Confirm OLED and 6 pin TDO position
- [x] Fit button labels arrow alignment
- [x] gojimmypi final ULX3S embossed link (swap, ulx3s on that side!)
- [x] check fan bracket vs USB strain relief on ULX3S side
- [x] Consider higher headers for more room
- [x] or consider arms to mount OLED display
- [x] Thin edges of stand plate
- [x] HDMI Stub-out
- [x] Move USB cable restraint to make room for HDMI internal cable
- [x] Adjust mounting pin USB side
- [x] Check button fit
- [x] Stabilize stand
- [x] Add new front stand clip (skipped, adjusted clips)
- [x] Consider moving chamfer for display mount clip.
- [x] Adjust OLED header Fit. Prior Header_Block_Perimeter = 1.45, updated to 1.5. Confirmed hole increase from 2.9 to 3 mm
- [x] Chamfer OLED post
- [x] Check M3 resize now at 3.1 from 3.05 holes
- [x] Add snap clip (skipped, adjusted clips)
- [x] Remove snap clip post at USB exit (skipped, adjusted clips)
- [x] Test 40 pin header in 12F angled!)
- [x] Create optional shorter stand
- [x] Add HDMI exit holes
- [x] HDMI hole reduces from 15.5 to 15
- [x] Alignment post hole anomalies (see depth)
- [x] Recheck stubout-sizing, USB
- [x] Panel thickness now 1.95
- [x] No display stubout board
- [x] Non-dev ULX3S Side (no cutouts) - will not do, but will add a full-panel stub-out
- [x] M2 - NOT M3 holes for OLED frame
- [x] Keyhole adapter should be a single piece; offset moved when thickness shrank to integral number of print layers: 1.95 mm
- [x] Add Adapter inserts in standoffs
- [x] Roadway restraints

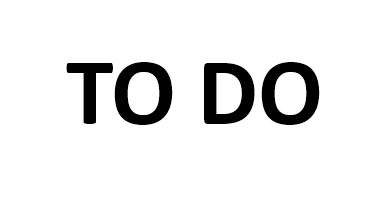
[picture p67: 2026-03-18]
images/TODO.jpg

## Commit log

2026-03-18 Initial Release
    [Adapter Base Plate Set.3mf, Adapter Base Plate Spacer 2.3mf, Adapter Base Plate Spacer 2.stl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]
2026-03-19 Refresh print sets with updated parts
    [Adapter Base Plate Set.3mf, Small parts.3mf, ULX3S Face Covers.3mf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]
2026-03-20 Update settings used: "0.15mm QUALITY @MK3 - ULX3S Project"
    [Adapter Base Plate Set.3mf, Adapter Base Plate Spacer 2.3mf, Adapter Base Plate Spacer.3mf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]
2026-03-26 Increase mounting bracket post width for enclosure stand. v39
    [Enclosure Display Side.3mf, Enclosure ULX3S Side.3mf]
2026-03-26 Polish readme and assembly instructions
2026-03-28 Add additional mounting adapter instructions
2026-03-29 Add missing Display Bracket Left and Right to Small Parts print set
    [Small parts.3mf]
2026-03-29 Add mounting adapter details
2026-03-29 Saved v39 parameters
    [ExportedParameters.csv]
2026-03-29 Add optional Hex Head Stand Mounting Plate and Display Brackets for hex head screw chamfer
    [Display Bracket Left (Hex Head).stl, Display Bracket Right (Hex Head).stl, Mounting Plate and Display Brackets (Heax Head).3mf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]
2026-04-02 Revised HDMI radius, add test fit parts
    [HDMI Part 1 Test.stl, HDMI Part 2 Test.stl, HDMI Stubout.stl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]
2026-04-02 Tighten HDMI hole fillet radius values
    [Enclosure Display Side.3mf, Enclosure ULX3S Side.3mf, ExportedParameters.csv]
2026-04-02 add heat set inserts pics
2026-04-03 Add printed enclosure image preview to README
2026-04-08 No changes, but reimported, resliced, as-reprinted test enclosure
    [Enclosure Display Side.3mf, Enclosure ULX3S Side.3mf]
2026-04-08 Updated stub-out and mock-up with slightly smaller HDMI radius
    [Display Mockup.3mf, Display Mockup.stl, HDMI Mockup Test.3mf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]
